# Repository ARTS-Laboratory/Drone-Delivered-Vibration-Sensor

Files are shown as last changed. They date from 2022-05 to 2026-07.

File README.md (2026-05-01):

# Drone Delivered Vibration Sensor
UAV deployable sensor package for vibration-based structural health monitoring.

<p align="center">
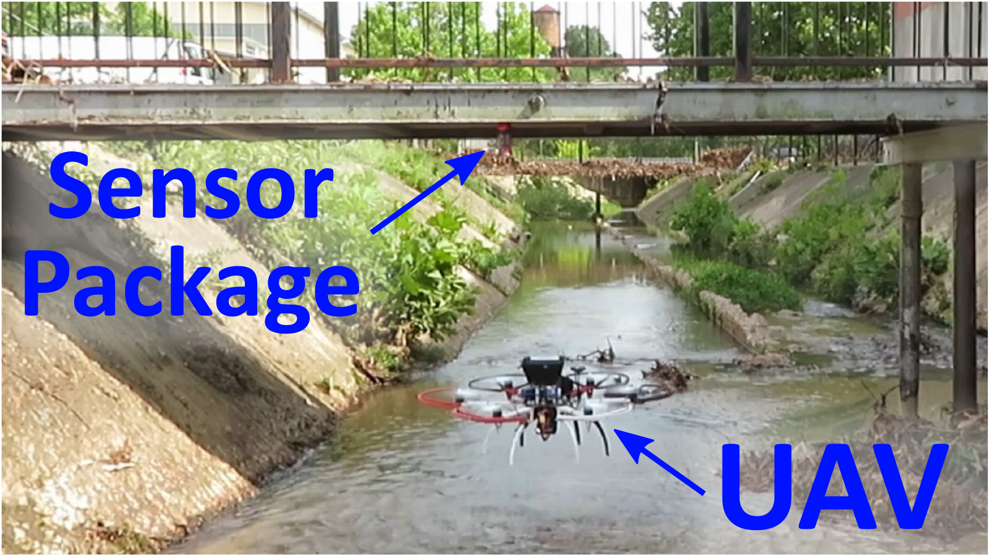
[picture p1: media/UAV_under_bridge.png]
UAV deploying sensor under bridge
  
</p>
<p align="center">
Figure 1: Video of UAV deploying a sensor package in the Rock Branch Creek at the University of South Carolina. UAV under manual control. Click the image to view the video on YouTube. 
</p>

## [System Design](System_design)
Vibration sensor package: includes sensor package software (Arduino) and hardware (circuit) files along with package frame design.

<br /><br /><br />

## Licensing and Citation

[][cc-by-sa]

This work is licensed under a
[Creative Commons Attribution-ShareAlike 4.0 International License][cc-by-sa].

[cc-by-sa]: http://creativecommons.org/licenses/by-sa/4.0/
[cc-by-sa-image]: https://licensebuttons.net/l/by-sa/4.0/88x31.png
[cc-by-sa-shield]: https://img.shields.io/badge/License-CC%20BY--SA%204.0-lightgrey.svg

Cite as:

@Misc{ARTSLabDroneDeliveredVibration,     
  author = {{ARTS-L}ab},  
  howpublished = {GitHub},    
  title  = {Drone Delivered Vibration Sensor},    
  groups = {{ARTS-L}ab},    
  url    = {https://github.com/ARTS-Laboratory/Drone-Delivered-Vibration-Sensor},   
  note = {Accessed: Month dd, yyyy},   
}

<p align="center">
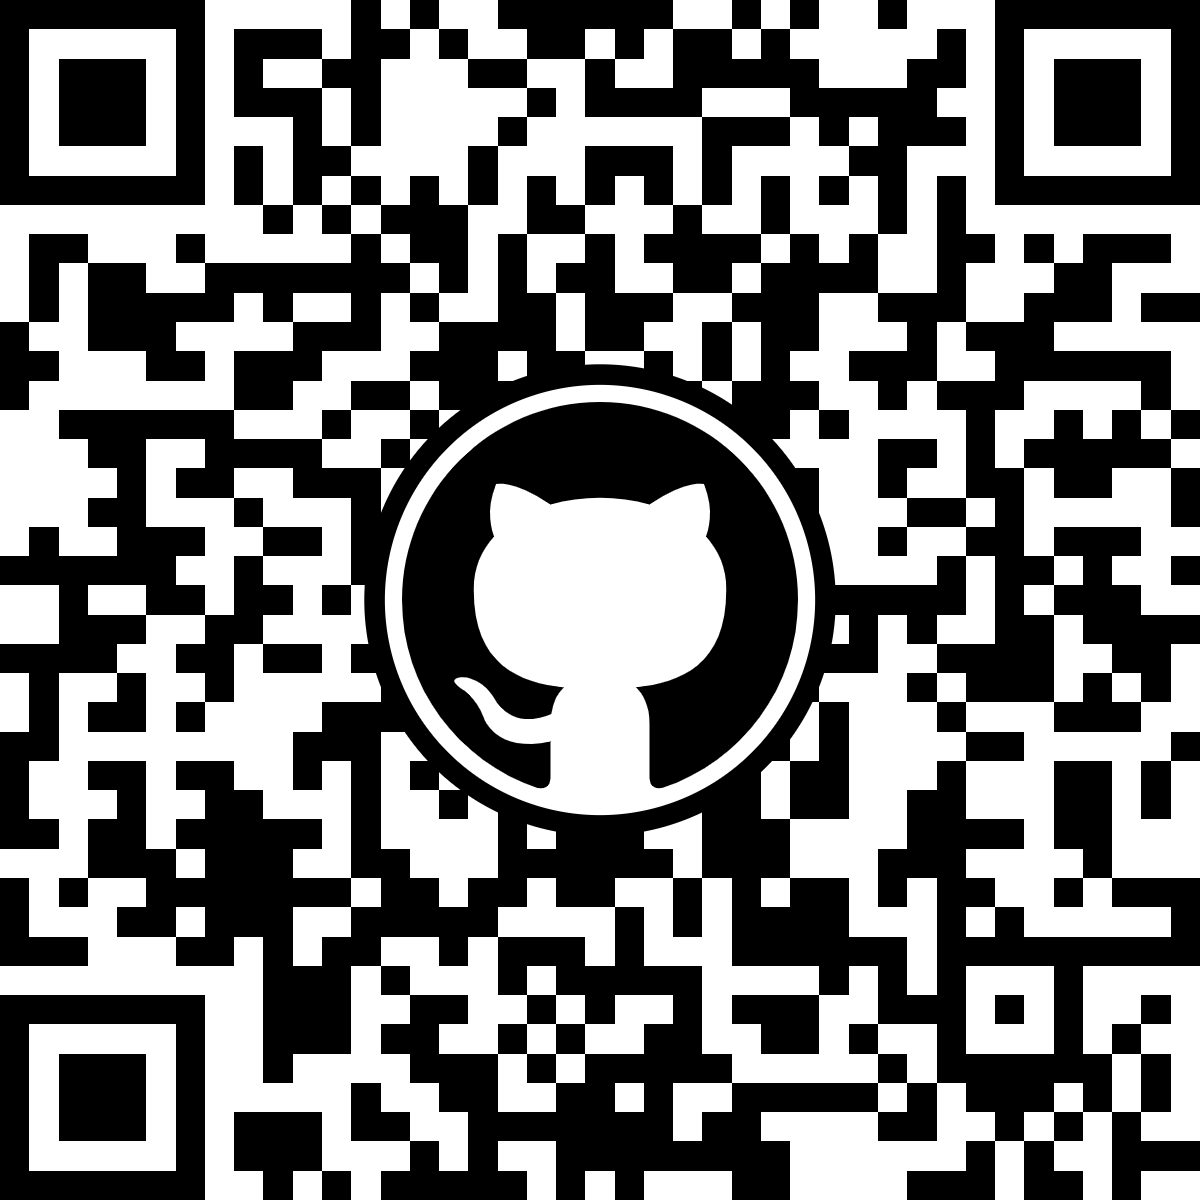
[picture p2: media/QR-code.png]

</p>
<p align="center">
QR code for repo.
</p>

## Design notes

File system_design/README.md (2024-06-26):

# System Design
The versions of the sensor package are all named after steel bridges.

## Forth
Records to local storage without wireless data transfer.

## Brooklyn
Designed for modal analysis using a network of sensors.

## Sydney Harbour
Automated frequency tracking and edge computing for rapid structural assessment. 

## Bayonne
Smart sensing node with online signal compensation.

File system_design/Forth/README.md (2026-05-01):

# Forth
Records to local storage without wireless data transfer.

## V0.1.0
A direct copy of Brooklyn V0.3 which included RTC and SD card, with no RF communication

## V0.2.0
Updated labels and silk screen symbols

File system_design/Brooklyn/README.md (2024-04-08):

# Brooklyn
Designed for modal analysis using a network of sensors.

## Version 0.1
1. Joud's Work
1. Basic package with wireless control. 

## Version 0.2
1. Ryan's Work
1. Focused on reducing package footprint while improving manufacturability.
1. Creating a stable package with options for different situations.

## Version 0.3
1. Ryan's Work
1. Same base package but includes RF and RTC for wireless synchronization.

## Version 0.4
1. Ryan's Work
1. Focused on improving the RF functionality.
1. More organized PCB.

## Version 0.5
1. Ryan's Work
1. Focused on multilayered PCB with the same base package.
1. In progress.

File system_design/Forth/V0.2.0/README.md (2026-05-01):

# Forth V0.2.0

* This uses kicad-9.0.5 -->  https://downloads.kicad.org/kicad/windows/explore/stable/download/kicad-9.0.5-x86_64.exe

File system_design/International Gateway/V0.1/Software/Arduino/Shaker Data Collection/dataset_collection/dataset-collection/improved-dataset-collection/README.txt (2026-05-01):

Author: Davis Breci
I was tasked to locate the cause for the variability of signal synchronization. The purpose of this file is to make a case for the modified dataset-collection.ino file included in this directory.

Within the original file's recordData function, the loop intended to collect data at fixed rate contained this line of code:
endTime = micros() + delayTime;
which calculates the end of each interval based on the start time of that interval.
This results in drift over time, as there is no constant reference point for timing. Consequently, the frequency of the data collection is less than 400Hz by a significant and variable amount.

This issue is addressed in the updated file.
The methodology is to synchronize the board's start time as much as possible, minimize the potential for random interruptions, and maintain a constant frequency by keeping time relative to the start time.
The start time delay measured with an oscilloscope is about 1-2ns, about one clock cycle on the Teensy 4.0.
All code that is not time-critical is executed outside the core data collection loop, particularly the slow Serial.println calls.
endTime is simply the start time + delayTime*(iterator).

Potential areas for improvement:
The most obvious thing to test is using a function generator as the trigger, rather than a wait loop.

Other files in this directory:
Screenshots of data taken with the updated code, with particular emphasis on the signals' minimally delayed response to a pulse, even 20+ seconds into recording.
A data csv file, and
A very crappy python script I used to make the plots.

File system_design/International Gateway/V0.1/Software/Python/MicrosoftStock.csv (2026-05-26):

index | date | open | high | low | close | volume | Name
390198 | 2013-02-08 | 27.35 | 27.71 | 27.31 | 27.55 | 33318306 | MSFT
390199 | 2013-02-11 | 27.65 | 27.92 | 27.5 | 27.86 | 32247549 | MSFT
390200 | 2013-02-12 | 27.88 | 28.0 | 27.75 | 27.88 | 35990829 | MSFT
390201 | 2013-02-13 | 27.93 | 28.11 | 27.88 | 28.03 | 41715530 | MSFT
390202 | 2013-02-14 | 27.92 | 28.06 | 27.87 | 28.04 | 32663174 | MSFT
390203 | 2013-02-15 | 28.04 | 28.16 | 27.875 | 28.01 | 49650538 | MSFT
390204 | 2013-02-19 | 27.8801 | 28.09 | 27.8 | 28.045 | 38804616 | MSFT
390205 | 2013-02-20 | 28.13 | 28.2 | 27.83 | 27.87 | 44109412 | MSFT
390206 | 2013-02-21 | 27.74 | 27.74 | 27.23 | 27.49 | 49078338 | MSFT
390207 | 2013-02-22 | 27.68 | 27.76 | 27.48 | 27.76 | 31425726 | MSFT
390208 | 2013-02-25 | 27.97 | 28.05 | 27.37 | 27.37 | 48011248 | MSFT
390209 | 2013-02-26 | 27.38 | 27.6 | 27.34 | 27.37 | 49917353 | MSFT
390210 | 2013-02-27 | 27.42 | 28.0 | 27.33 | 27.81 | 36390889 | MSFT
390211 | 2013-02-28 | 27.88 | 27.97 | 27.74 | 27.8 | 35836861 | MSFT
390212 | 2013-03-01 | 27.72 | 27.98 | 27.52 | 27.95 | 34849287 | MSFT
390213 | 2013-03-04 | 27.85 | 28.15 | 27.7 | 28.15 | 38163549 | MSFT
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

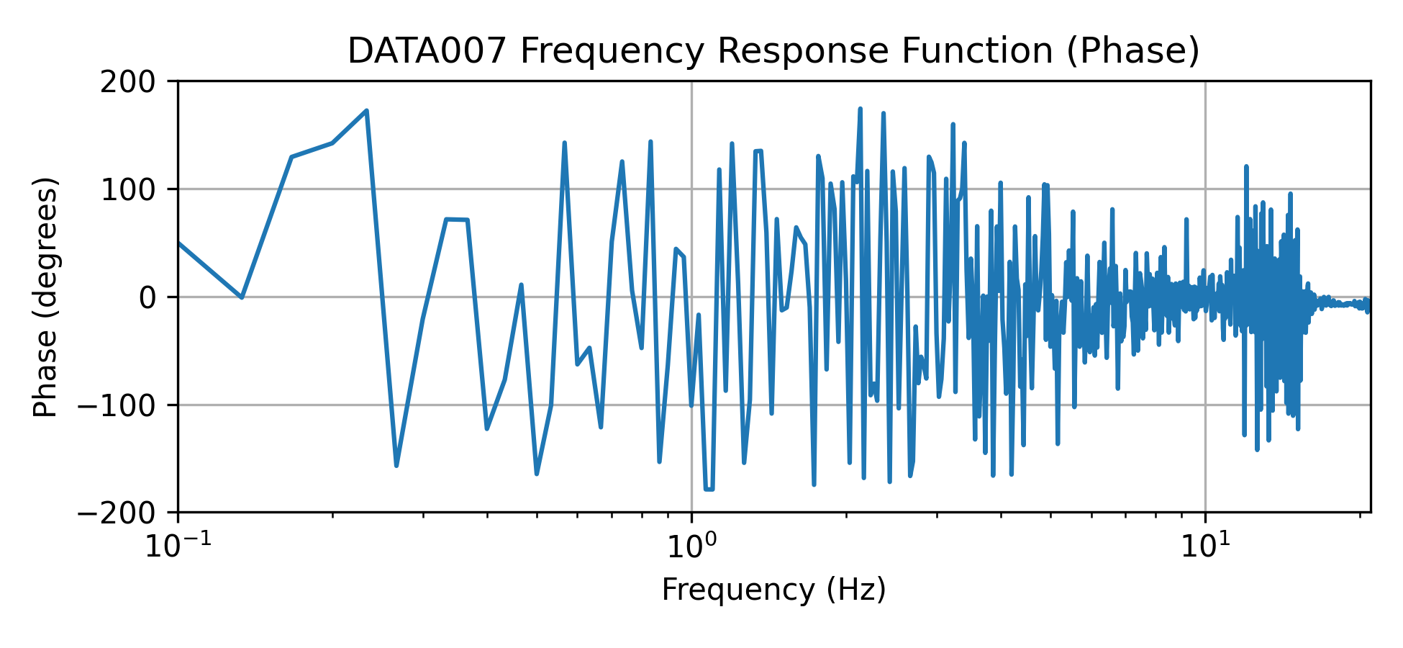
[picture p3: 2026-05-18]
system_design/International Gateway/V0.1/Software/Arduino/Shaker Data Collection/DATA007_FRF_Phase.png

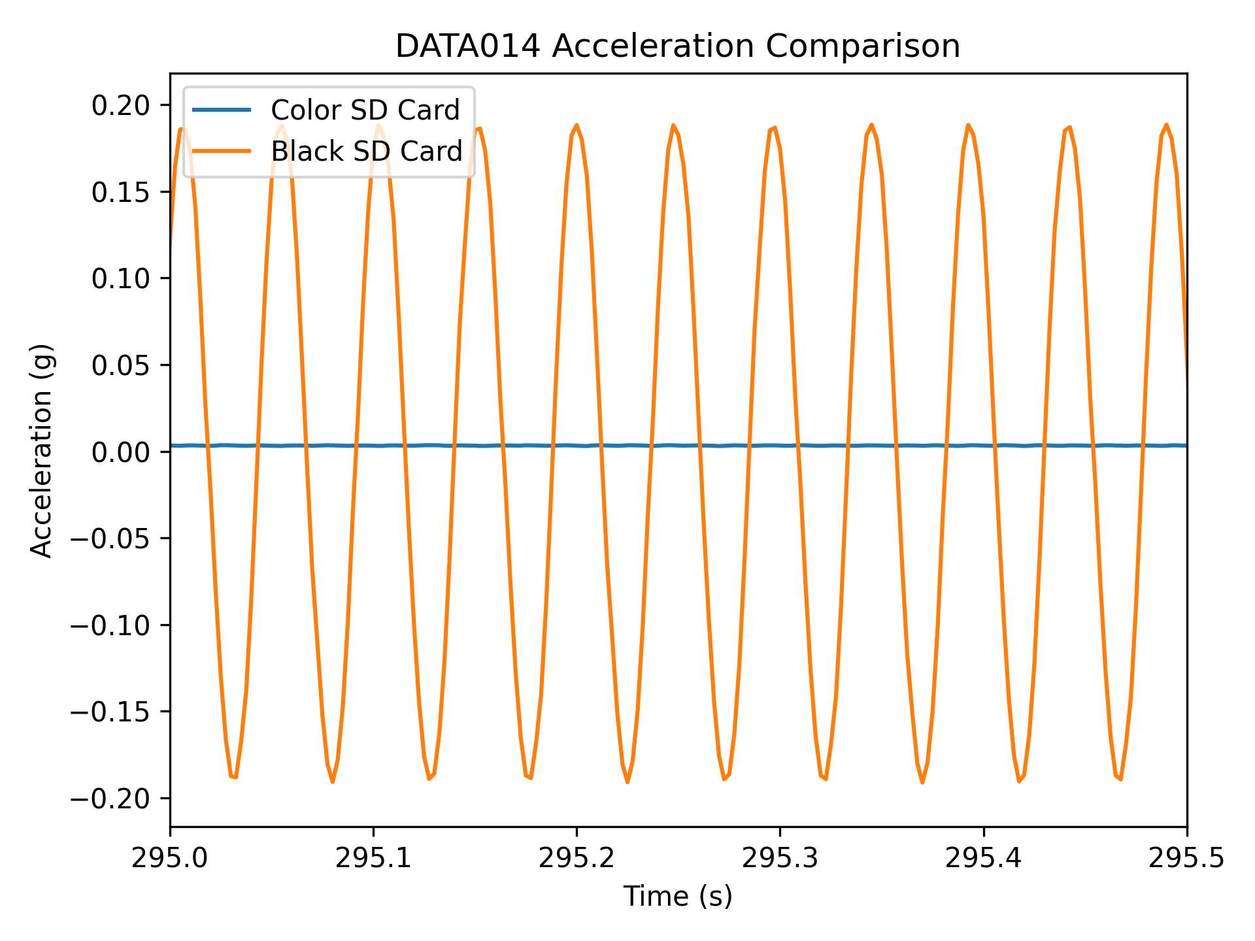
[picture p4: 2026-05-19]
system_design/International Gateway/V0.1/Software/Arduino/Shaker Data Collection/DATA014_Zoomed_Acceleration_Comparison.png

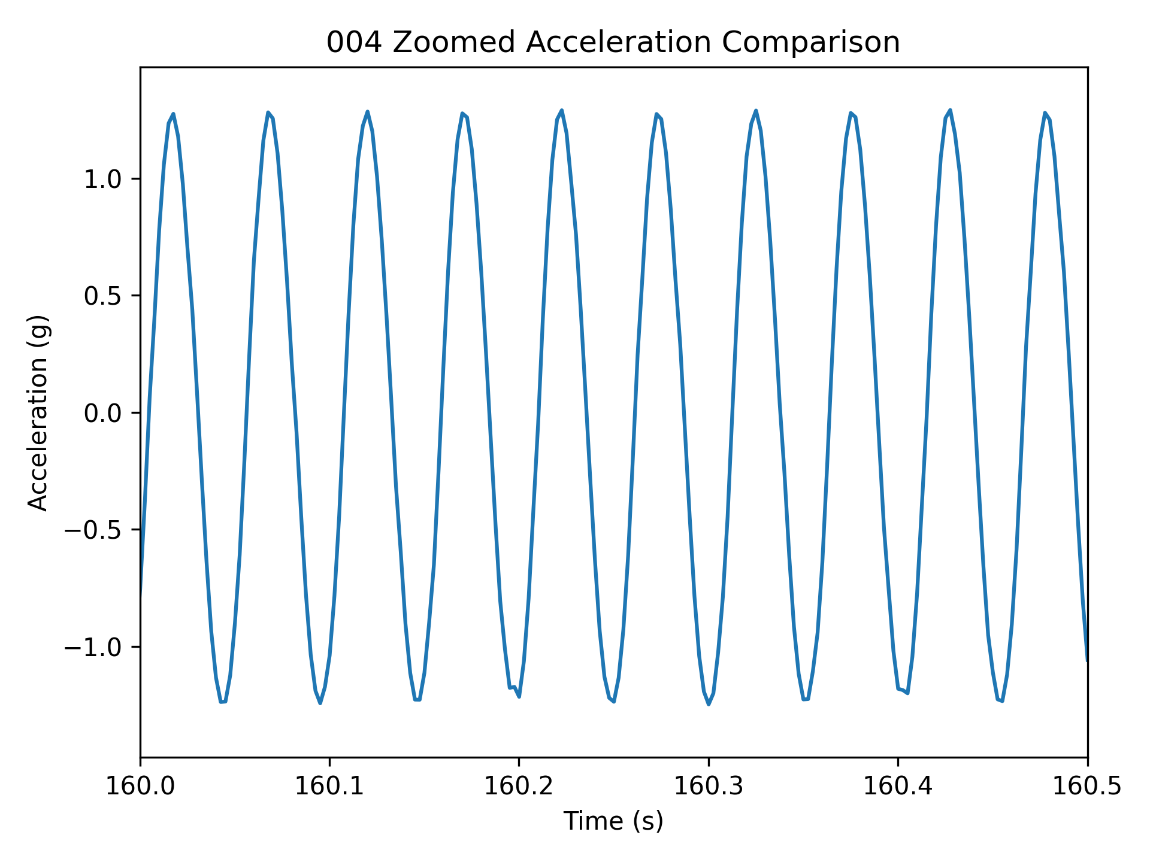
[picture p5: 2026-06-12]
system_design/International Gateway/V0.1/Software/Arduino/Shaker Data Collection/004_160_Acceleration_Comparison.png

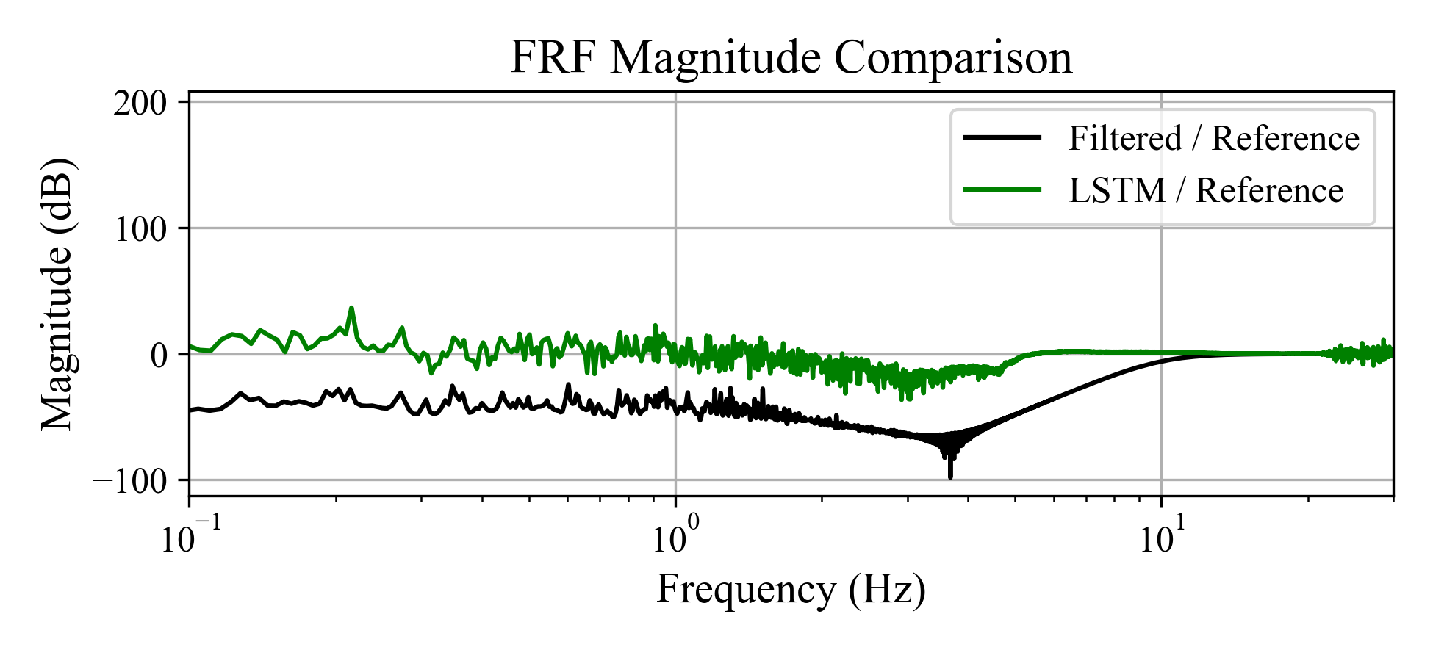
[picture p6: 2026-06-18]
system_design/International Gateway/V0.1/Software/Arduino/Shaker Data Collection/005_100Epoch_FRF_Magnitude_Comparison.png

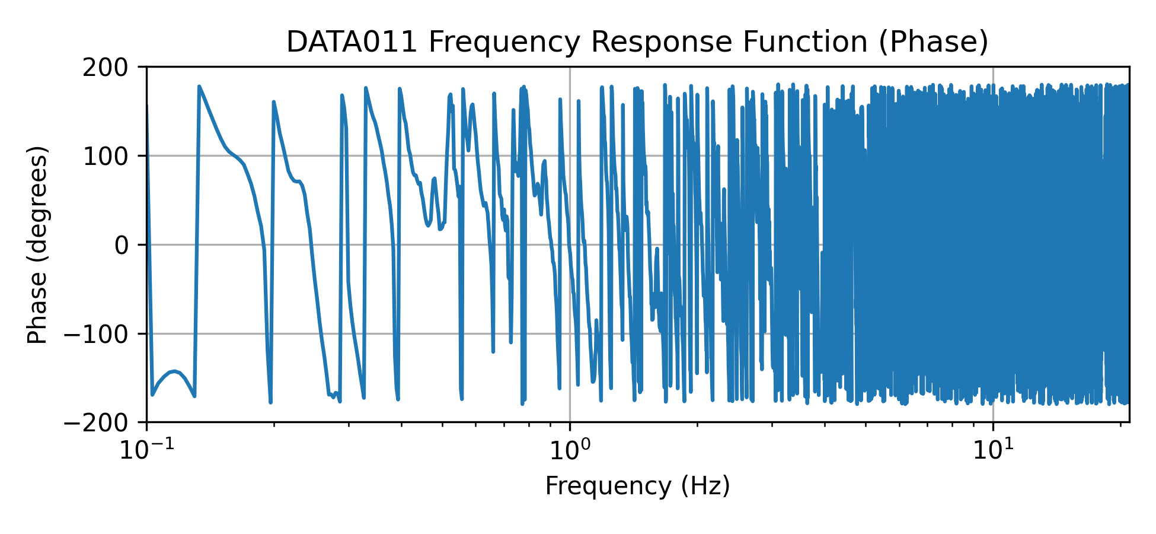
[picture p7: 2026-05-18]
system_design/International Gateway/V0.1/Software/Arduino/Shaker Data Collection/DATA011_FRF_Phase.png

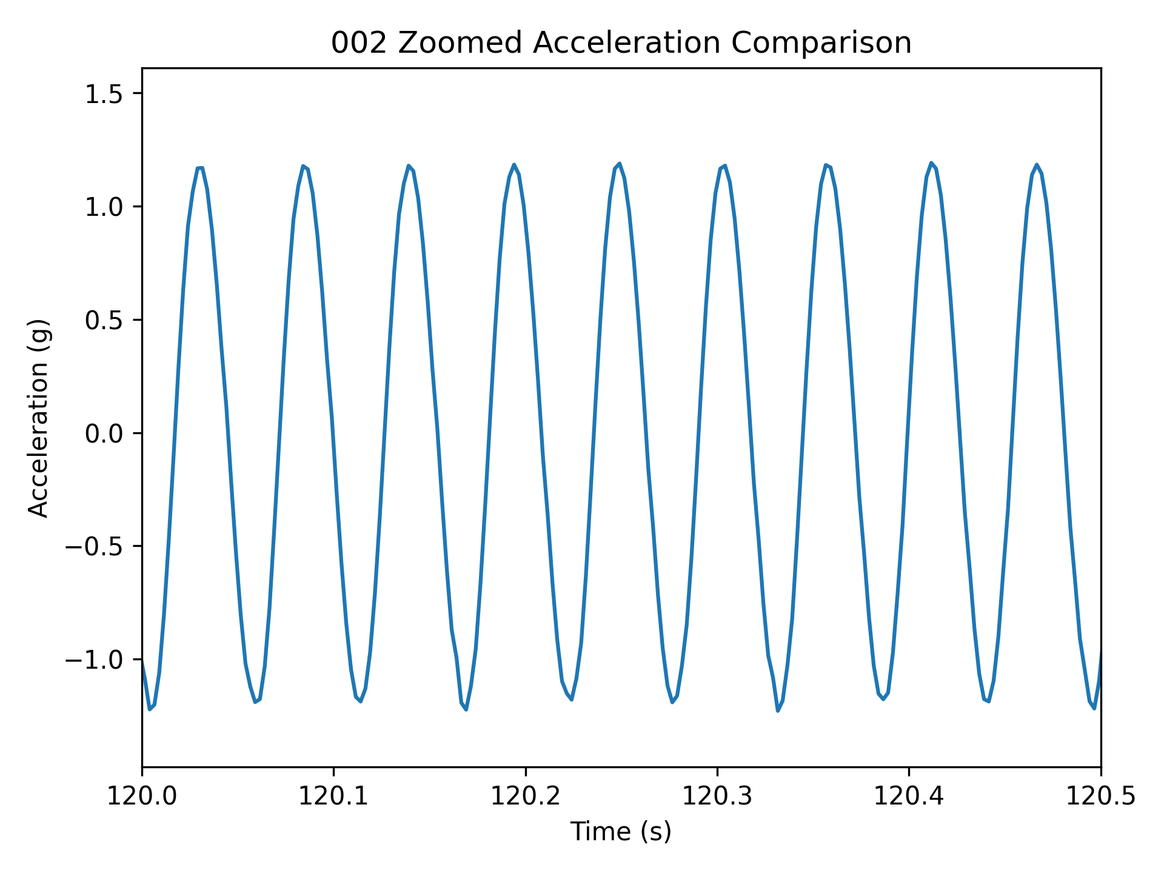
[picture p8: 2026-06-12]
system_design/International Gateway/V0.1/Software/Arduino/Shaker Data Collection/002_120_Acceleration_Comparison.png

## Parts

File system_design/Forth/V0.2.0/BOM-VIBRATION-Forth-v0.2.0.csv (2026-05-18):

Designator | Component | Amount in Inventory | Amount Per Package | Individual Cost | Total Cost | Vendor 1 | Vendor 2 | Vendor 3 | Vendor 4 | Vendor 5 | Vendor 6
Teesny 4.0 | Teensy 4.0 Development Board | 0 | 1 | 23.99 | 23.99 | https://www.digikey.com/en/products/detail/sparkfun-electronics/15583/10384551 | https://www.digikey.com/en/products/detail/sparkfun-electronics/28368/26266461 | https://www.microcenter.com/product/699942/TEENSY_40_Development_Board;_ARM_Cortex-M7_at_600_MHz;_1984K_Flash;_1024K_RAM_(512K_tightly_coupled);_1K_EEPROM | https://www.sparkfun.com/teensy-4-0.html
3-Axis Accelerometer | SCA3300 D01 | 3 | 1 | 36 | 36 | https://www.digikey.com/en/products/detail/murata-electronics/SCA3300-D01-1/7035232?gclsrc=aw.ds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 | https://www.mouser.com/ProductDetail/Murata-Electronics/SCA3300-D01-1?qs=u4fy%2FsgLU9PJXg1inqbWiw%3D%3D&mgh=1 | https://www.mouser.com/ProductDetail/Murata-Electronics/SCL3300-D01-10?qs=gZXFycFWdAOFydYBLsvu8Q%3D%3D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
Micro SD card slot/tray | MICROSD CARD BFF QT PY/XIAO | 0 | 1 | 6.5 | 6.5 | https://www.digikey.com/en/products/detail/sparkfun-electronics/13743/5881845?gclsrc=aw.ds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 | https://www.digikey.com/en/products/detail/adafruit-industries-llc/5683/18073185?gclsrc=aw.ds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 | https://abra-electronics.com/robotics-embedded-electronics/breakout-boards/storage/bb-microsd-tf-micro-sd-card-board-3-3v-mini-tf.html | https://www.amazon.com/ANMBEST-Adapter-Interface-Conversion-Arduino/dp/B08CMLG4D6
DS3231 real-time clock | DS3231M+ | 1 | 1 | 11.96 | 11.96 | https://www.digikey.com/en/products/detail/analog-devices-inc-maxim-integrated/DS3231M/2402420 | https://www.mouser.com/ProductDetail/Analog-Devices-Maxim-Integrated/DS3231M%2b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
N42 permanent magnet | Q063L-N42 | 1-1/2"L x 1-1/2"W x 1/16"T Neodymium Block Magnet | 0 | 1 | 6.46 | 6.46 | https://www.kjmagnetics.com/dx46-neodymium-disc-magnet
2s 7.4V LiPo battery | Zeee 2S Lipo Battery 1500mAh 7.4V 60C with Deans Plug | 0 | 1 | 18 | 18 | https://zeeebattery.com/products/zeee-7-4v-60c-1500mah-2s-lipo-battery-deans-plug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 | https://www.digikey.com/en/products/detail/sparkfun-electronics/11855/5271297?gclsrc=aw.ds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 | https://www.ebay.com/itm/374993811392?chn=ps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
CR-1025 3V Li+ coin cell | CR-1025-ND | 0 | 1 | 1.09 | 1.09 | https://www.digikey.com/en/products/detail/panasonic-energy/CR-1025-BN/269738 | https://www.ebay.com/itm/365610739537?chn=ps&google_free_listing_action=view_item
RTC coin cell holder | 2718 | 1 | 1 | 1.61 | 1.61 | https://www.digikey.com/en/products/detail/kitronik-ltd/2718/8635448 | https://www.mouser.com/ProductDetail/Harwin/S8211-46R?qs=Qom7kyPojXb0DJM7n6BsBw%3D%3D&mgh=1
Main PCB | Main board | 0 | 1 | 8.23 | 8.23 | https://oshpark.com/
Slide switch | SPDT | 1 | 1 | 0.38 | 0.38 | https://www.digikey.com/en/products/detail/same-sky-formerly-cui-devices/SLW-129956-4A-RA-N-D/24399223
Micro SD card | Gigastone 8GB 10-Pack Micro SD Card, Full HD Video 80MB/s Micro SDHC Class 10 | 0 | 1 | 8.24 | 8.24 | https://www.staples.com/centon-micro-8gb-sdhc-memory-card-uhs1-5-pack-s1-msdhu1-8g-5-b/product_24298979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 | https://www.staples.com/transcend-8gb-microsdhc-memory-card-class-10-ts8gusdhc10/product_IM1LK3226 | https://www.cdwg.com/product/transcend-flash-memory-card-8-gb-microsd/3181432?pfm=srh | https://www.cdwg.com/product/kingston-industrial-flash-memory-card-8-gb-microsdhc-uhs-i/6669743?pfm=srh | https://business.walmart.com/ip/Gigastone-8GB-Micro-SD-Card-FHD-Video-UHS-I-U1-Class-10-Surveillance-Security-Action-Cameras-Drone-Dash-Cams-5-Pack-5x8GB-GS-2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 | https://www.amazon.com/Gigastone-10-Pack-Surveillance-Security-Action/dp/B0876H387X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
LED | L314ED | 1 | 1 | 0.2 | 0.2 | https://www.digikey.com/en/products/detail/liteon/LTL-4231N/214440 | https://www.lvelectronics.com/details/item?itemid=AOP%20L314ED
Resistors | RES SMD 221 OHM 1% 1/4W 1206 | 10 | 1 | 0.1 | 0.1 | https://www.digikey.com/en/products/detail/bourns-inc/CR1206-FX-2210ELF/2562869
Capacitors 0.1uF | C1206S104K5RACAUTO 0.1 uF 10% 50V Ceramic Capacitor X7R 1206 (3216 Metric) | 10 | 4 | 0.48 | 1.92 | https://www.digikey.com/en/products/detail/kemet/C1206S104K5RACAUTO/10232834 | https://www.mouser.com/ProductDetail/KEMET/C1206S104K5RACAUTO?qs=ds50AKTGxA9C%252BOGFjvBCPg%3D%3D
Fuse board | SF-0603S050-2 | 5 | 1 | 0.68 | 0.68 | https://www.digikey.com/en/products/detail/bourns-inc/SF-0603S050-2/2563500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
3.3V regulator | TC1262-3.3VDBTR | 1 | 1 | 0.69 | 0.69 | https://www.digikey.com/en/products/detail/microchip-technology/TC1262-3-3VDBTR/443194
5V regulator | MIC5239-5.0YS-TR | 2 | 1 | 3.58 | 3.58 | https://www.digikey.com/en/products/detail/microchip-technology/MIC5239-5-0YS-TR/2346595 | https://www.microchipdirect.com/product/MIC5239-5.0YS-TR | https://www.mouser.com/ProductDetail/Microchip-Technology/MIC5239-5.0YS-TR?qs=U6T8BxXiZAVR02O8mv9RNQ%3D%3D
M2 nut | M2 nut | 100 | 3 | 2.37 | 7.11 | https://www.grainger.com/product/Hex-Nut-Std-Hex-22UK72?opr=ILOF
M2 bolt | M2 bolt | 100 | 3 | 6.92 | 20.76 | https://www.grainger.com/product/Machine-Screw-M2x0-40-Thread-856Z51
 |  |  |  | Total Cost | 157.5

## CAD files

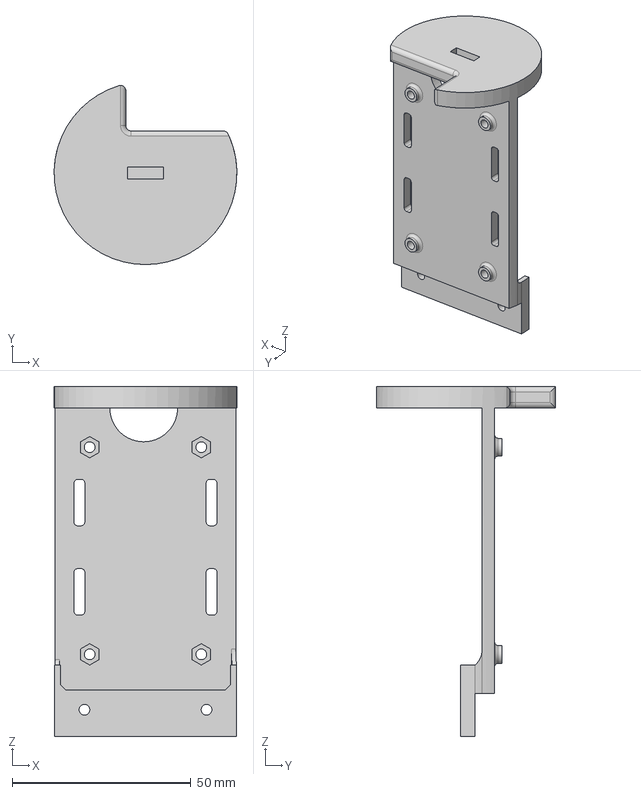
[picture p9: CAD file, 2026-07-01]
system_design/Forth/V0.2.0/Hardware/CAD/sensor frame/Part4Updated.step
51.2 x 50.2 x 98.0 mm

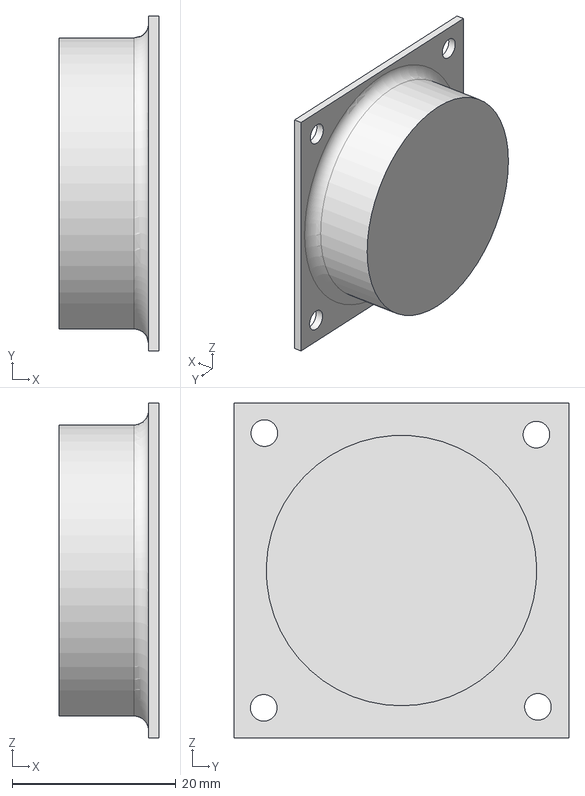
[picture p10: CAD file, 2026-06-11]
system_design/Forth/V0.2.0/Hardware/CAD/sensor frame/MagnetCap.stp
12.2 x 40.9 x 40.9 mm

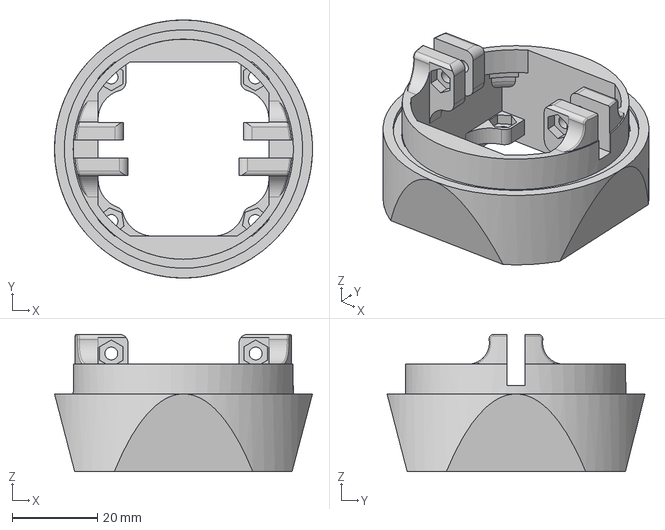
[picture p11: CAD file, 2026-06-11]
system_design/Forth/V0.2.0/Hardware/CAD/sensor frame/Part4Bottom.step
60.6 x 60.6 x 32.3 mm

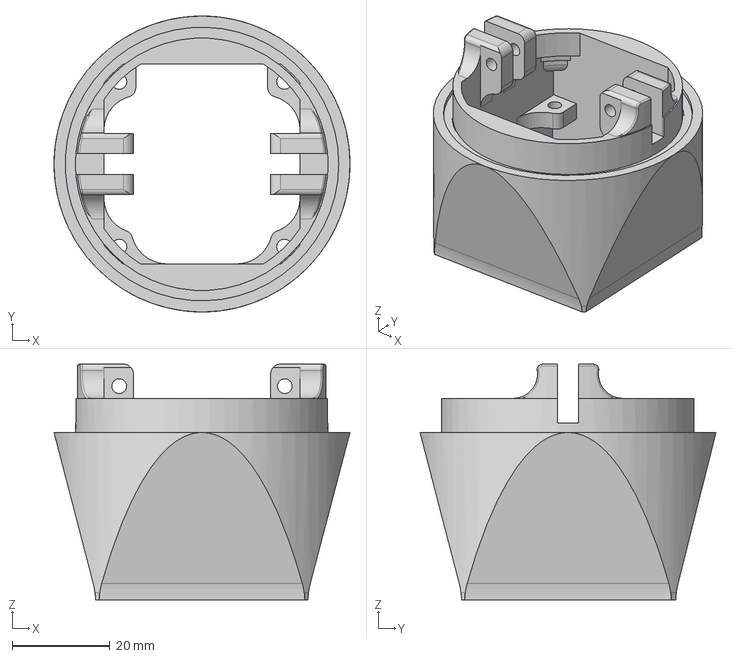
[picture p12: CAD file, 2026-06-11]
system_design/Forth/V0.2.0/Hardware/CAD/sensor frame/Part4OtherBottom.step
60.6 x 60.6 x 48.3 mm

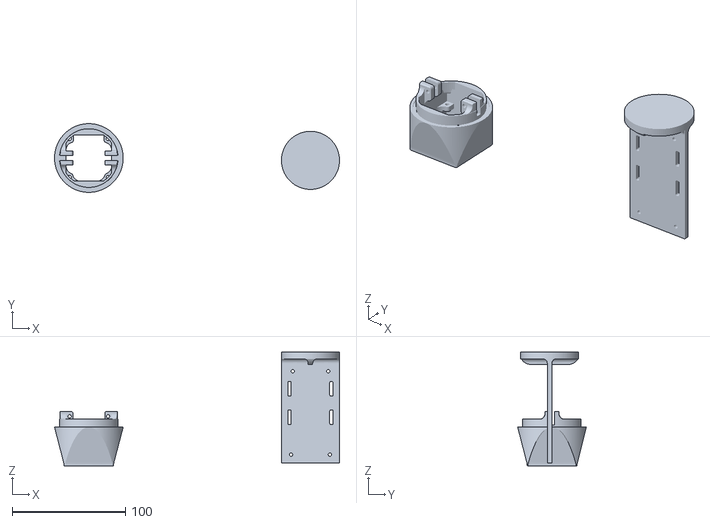
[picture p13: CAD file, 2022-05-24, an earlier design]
system_design/Forth/V0.1.0/Hardware/Frame/Sensor Package Housing Unit.stl
251.3 x 60.6 x 100.5

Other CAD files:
system_design/Forth/V0.2.0/Hardware/CAD/sensor frame/Part4Switch.step
system_design/Forth/V0.2.0/Hardware/CAD/sensor frame/Part4.step
system_design/Forth/V0.1.0/Hardware/Frame/PCB_HousingUnit.f3d
system_design/Forth/V0.2.0/Hardware/CAD/sensor frame v1.f3d
system_design/Forth/V0.2.0/Hardware/CAD/sensor frame/Component2.ipt
system_design/Forth/V0.2.0/Hardware/CAD/sensor frame/MagnetCap.3mf
system_design/Forth/V0.2.0/Hardware/CAD/sensor frame/MagnetCap.ipt
system_design/Forth/V0.2.0/Hardware/CAD/sensor frame/OldVersions/MagnetCap.0003.ipt
system_design/Forth/V0.2.0/Hardware/CAD/sensor frame/OldVersions/UpatedSensorFrame.0001.ipt
system_design/Forth/V0.2.0/Hardware/CAD/sensor frame/Part4.ipt
system_design/Forth/V0.2.0/Hardware/CAD/sensor frame/UpatedSensorFrame.ipt
system_design/Forth/V0.2.0/Hardware/CAD/sensor frame/sensor frame.iam
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

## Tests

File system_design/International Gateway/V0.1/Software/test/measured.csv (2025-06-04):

-2.875130916445163901e-02
-4.373330916445163086e-02
-5.736130916445163208e-02
-7.172630916445163485e-02
-8.455330916445163991e-02
-9.480730916445163914e-02
-1.020343091644516365e-01
-1.067743091644516445e-01
-1.104643091644516434e-01
-1.125543091644516380e-01
-1.126743091644516470e-01
-1.100943091644516342e-01
-1.055243091644516434e-01
-9.955630916445164236e-02
-9.281130916445164136e-02
-8.460030916445164528e-02
-7.443930916445164192e-02
-6.330030916445164579e-02
-5.093430916445163686e-02
-3.915230916445163606e-02
-2.658830916445163728e-02
-1.131230916445163590e-02
3.898990835548364186e-03
1.778269083554836344e-02
3.148369083554836828e-02
4.683369083554836387e-02
6.213469083554836597e-02
7.449469083554835502e-02
8.573069083554836489e-02
9.728269083554835772e-02
1.058856908355483573e-01
1.126156908355483571e-01
1.175056908355483626e-01
1.199556908355483564e-01
1.188156908355483543e-01
1.151456908355483616e-01
1.099656908355483576e-01
1.018656908355483615e-01
9.194869083554835232e-02
8.118969083554836152e-02
6.926369083554835548e-02
5.594369083554836392e-02
4.069269083554836325e-02
2.445669083554836282e-02
6.941890835548363177e-03
-9.103809164451635502e-03
-2.431930916445163710e-02
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

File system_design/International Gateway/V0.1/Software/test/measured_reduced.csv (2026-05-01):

-6.413430916445164720e-02
-6.432130916445163993e-02
-6.292430916445164446e-02
-6.076230916445163333e-02
-5.911530916445163070e-02
-5.748930916445163519e-02
-5.469330916445163532e-02
-5.154430916445163630e-02
-4.708130916445163461e-02
-4.368630916445163243e-02
-3.841530916445163452e-02
-3.396930916445163595e-02
-2.946730916445163689e-02
-2.436130916445163747e-02
-1.841330916445163557e-02
-1.218430916445163541e-02
-5.102909164451636427e-03
9.202608355483637894e-04
7.673390835548363556e-03
1.378769083554836489e-02
2.134169083554836310e-02
2.827069083554836423e-02
3.308869083554836360e-02
3.936669083554836940e-02
4.541169083554836422e-02
5.065969083554836688e-02
5.374269083554836929e-02
5.919869083554836486e-02
6.343769083554835764e-02
6.479769083554835774e-02
6.781969083554835465e-02
6.835469083554836234e-02
6.851769083554835882e-02
6.703769083554836361e-02
6.555569083554835252e-02
6.378769083554836072e-02
5.989669083554836904e-02
5.734269083554836832e-02
5.345069083554836870e-02
4.822969083554836528e-02
4.396669083554836932e-02
3.818169083554836390e-02
3.188969083554836492e-02
2.446069083554836335e-02
1.947469083554836250e-02
1.164069083554836528e-02
3.427990835548364121e-03
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

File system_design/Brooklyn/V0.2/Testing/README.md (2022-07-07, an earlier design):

# Testing For V0.2 of the Vibration Sensor

<p align="center">
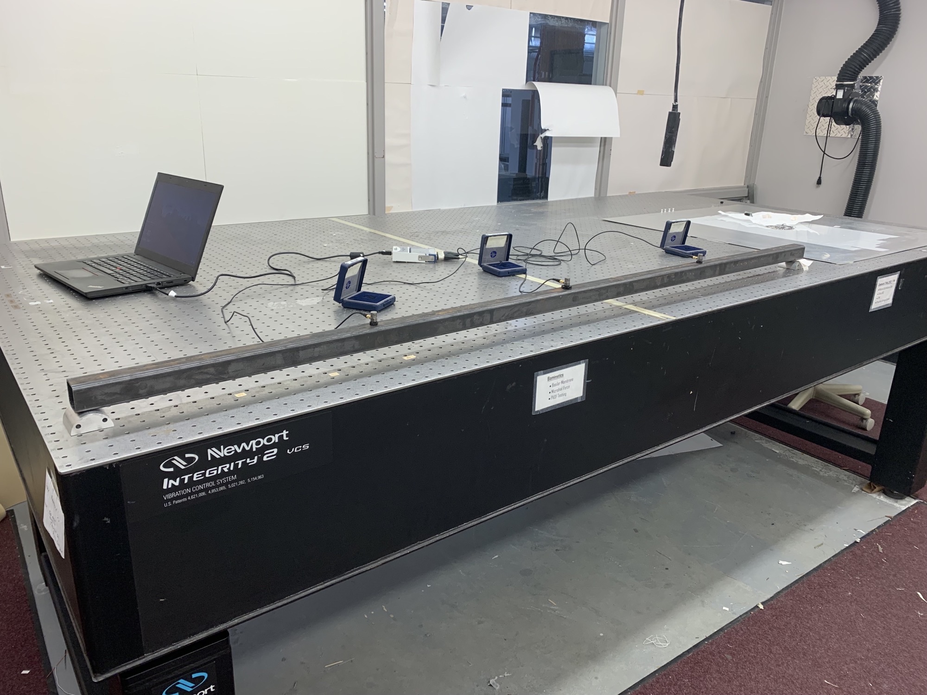
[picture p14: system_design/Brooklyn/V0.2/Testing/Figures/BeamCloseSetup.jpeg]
Beam Close Test Setup
</a> 
<p align="center">
Figure 1: Picture of the beam test with accelerometers in a close position

<p align="center">
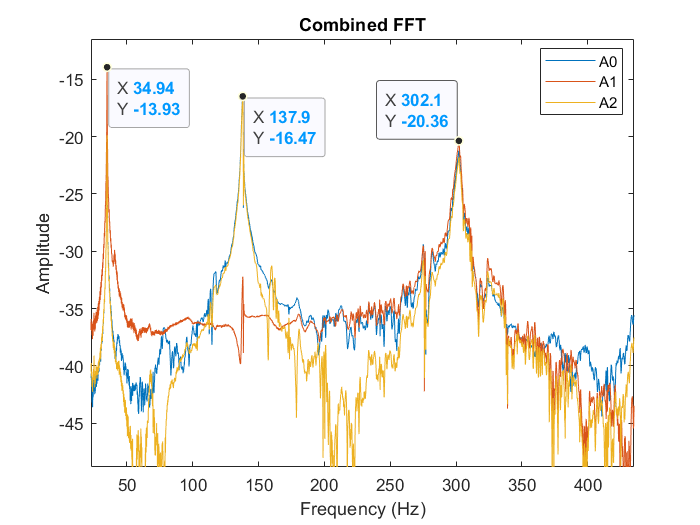
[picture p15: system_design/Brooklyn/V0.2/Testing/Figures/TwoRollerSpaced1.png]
Two Roller Spaced Test 1
</a> 
<p align="center">
Figure 2: FFT of the beam test with spaced out accelerometers and two roller supports

<p align="center">
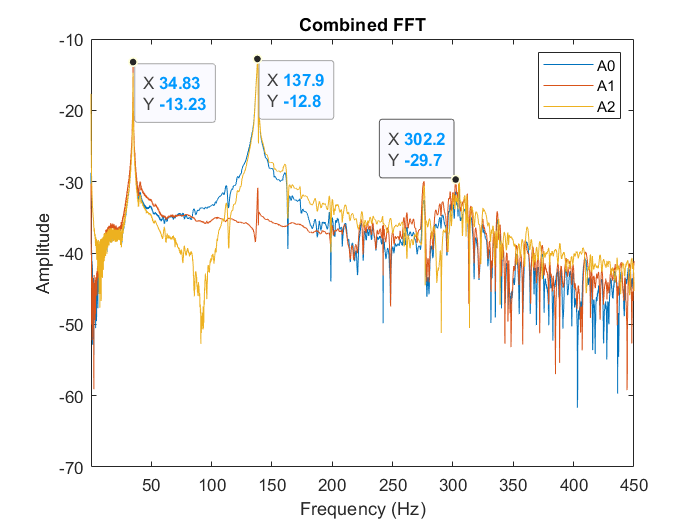
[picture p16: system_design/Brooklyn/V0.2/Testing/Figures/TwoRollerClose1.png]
Two Roller Close Test 1
</a> 
<p align="center">
Figure 3: FFT of the beam test with close accelerometers and two roller supports

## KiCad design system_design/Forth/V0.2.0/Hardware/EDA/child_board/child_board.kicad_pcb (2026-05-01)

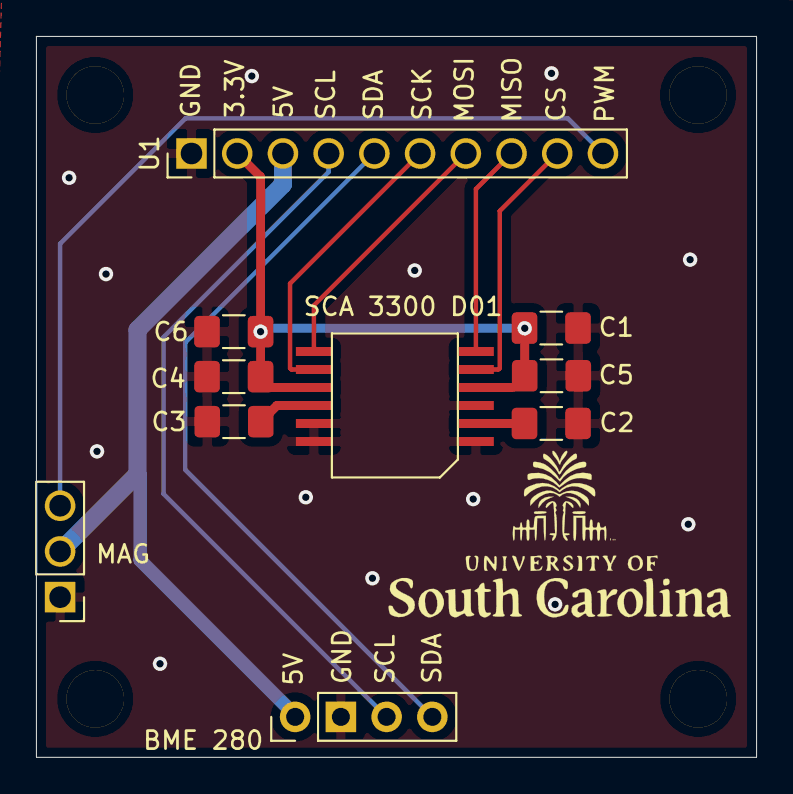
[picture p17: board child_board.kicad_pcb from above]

Board: 2 copper layers, 40.0 x 40.0 mm, 15 parts (0 on the bottom side), 12 nets.

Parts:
., .#2, .#3, .#5: MountingHole_3.2mm_M3_DIN965_Pad
.#4: .; uofsc_logo_0_75in
BME 280: BME; PinHeader_1x04_P2.54mm_Vertical
C1, C2, C3, C4, C5, C6: C_Small; C_1206_3216Metric_Pad1.42x1.75mm_HandSolder
MAG: Conn_01x03_Female; PinHeader_1x03_P2.54mm_Vertical
SCA 3300 D01: SCA_330_X1; SCA-3300 X1
U1: 10PinConnector; PinHeader_1x10_P2.54mm_Vertical

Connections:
+3V3: C1.1, C4.1, C5.2, C6.1, SCA 3300 D01.4, SCA 3300 D01.9, U1.2
GND: BME 280.2, C1.2, C2.1, C3.1, C4.2, C5.1, C6.2, MAG.1, SCA 3300 D01.1, SCA 3300 D01.3, SCA 3300 D01.11, SCA 3300 D01.12, U1.1
unnamed: C2.2, SCA 3300 D01.2
unnamed: C3.2, SCA 3300 D01.10
unnamed: BME 280.1, MAG.2, U1.3
unnamed: MAG.3, U1.10
unnamed: BME 280.3, U1.4
unnamed: BME 280.4, U1.5
unnamed: SCA 3300 D01.8, U1.6
unnamed: SCA 3300 D01.7, U1.7
unnamed: SCA 3300 D01.6, U1.8
unnamed: SCA 3300 D01.5, U1.9

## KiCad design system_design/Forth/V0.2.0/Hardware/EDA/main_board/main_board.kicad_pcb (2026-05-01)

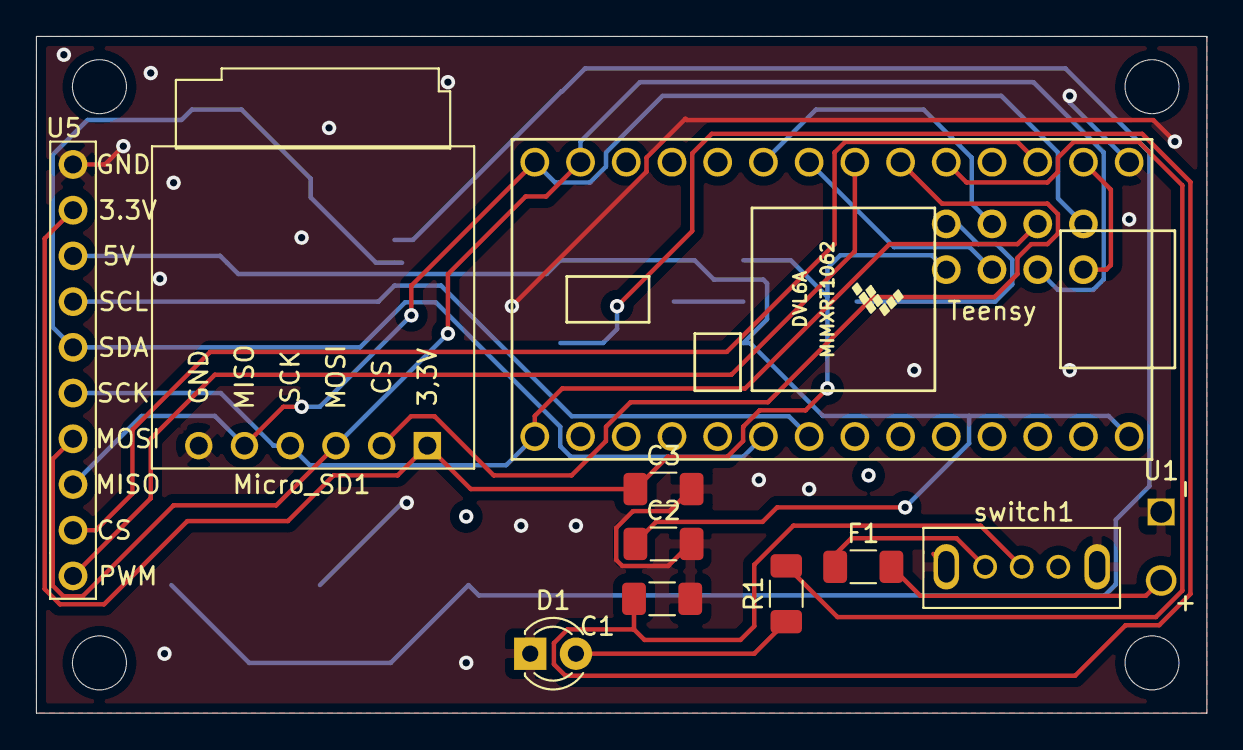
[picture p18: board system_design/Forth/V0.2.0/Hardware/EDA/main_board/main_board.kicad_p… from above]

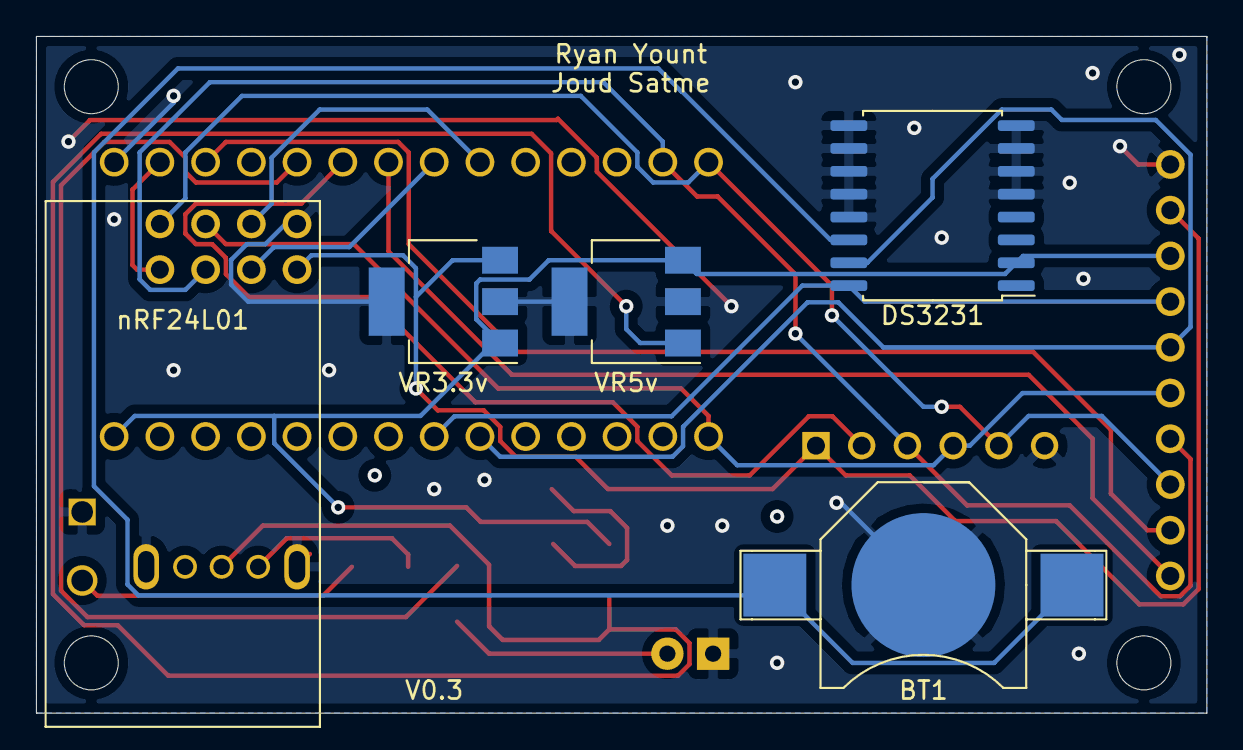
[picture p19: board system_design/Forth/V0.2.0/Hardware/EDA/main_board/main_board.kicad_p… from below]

Board: 2 copper layers, 65.0 x 37.6 mm, 16 parts (5 on the bottom side), 20 nets.

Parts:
BT1: Battery_Cell; battery_holder_10mm
C1, C2, C3: C; C_1206_3216Metric_Pad1.33x1.80mm_HandSolder
D1: LED; LED_D3.0mm
DS3231: DS3231M; SOIC-16W_7.5x10.3mm_P1.27mm
F1: Fuse; C_1206_3216Metric_Pad1.33x1.80mm_HandSolder
Micro_SD1: microSD_small; small_microSD_v2
R1: R; R_1206_3216Metric_Pad1.30x1.75mm_HandSolder
Teensy: Teensy4.0-teensy; teensy4.0
U1: power_input; XT60PW
U5: main_board_top_rail; top_rail
VR3.3v, VR5v: AP7361C-33E; SOT-223-3_TabPin2
nRF24L01: nRF24L01+
switch1: grounded_DIP_switch; grounded_switch

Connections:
GND: BT1.2, C1.2, C2.2, C3.2, D1.1, DS3231.5, DS3231.6, DS3231.7, DS3231.8, DS3231.9, DS3231.10, DS3231.11, DS3231.12, DS3231.13, Micro_SD1.6, Teensy.1, U1.1, U5.9, VR3.3v.2, VR5v.2, nRF24L01.5, switch1.4, switch1.5
unnamed: BT1.1, DS3231.14
unnamed: C1.1, VR5v.1, switch1.2
unnamed: C2.1, DS3231.2, Teensy.33, U5.7, VR3.3v.1, VR5v.3
unnamed: C3.1, Micro_SD1.1, U5.8, VR3.3v.3, nRF24L01.1
unnamed: D1.2, R1.1
unnamed: F1.1, switch1.1
unnamed: F1.2, U1.2
unnamed: Micro_SD1.2, Teensy.6
unnamed: Micro_SD1.3, Teensy.13, U5.3, nRF24L01.3
unnamed: Micro_SD1.4, Teensy.20, U5.4, nRF24L01.7
unnamed: Micro_SD1.5, Teensy.14, U5.2, nRF24L01.8
unnamed: R1.2, Teensy.5
unnamed: Teensy.2, nRF24L01.4
unnamed: Teensy.3, U5.1
unnamed: Teensy.7, U5.10
unnamed: Teensy.8, nRF24L01.2
unnamed: Teensy.9, nRF24L01.6
unnamed: DS3231.15, Teensy.25, U5.5
unnamed: DS3231.16, Teensy.26, U5.6

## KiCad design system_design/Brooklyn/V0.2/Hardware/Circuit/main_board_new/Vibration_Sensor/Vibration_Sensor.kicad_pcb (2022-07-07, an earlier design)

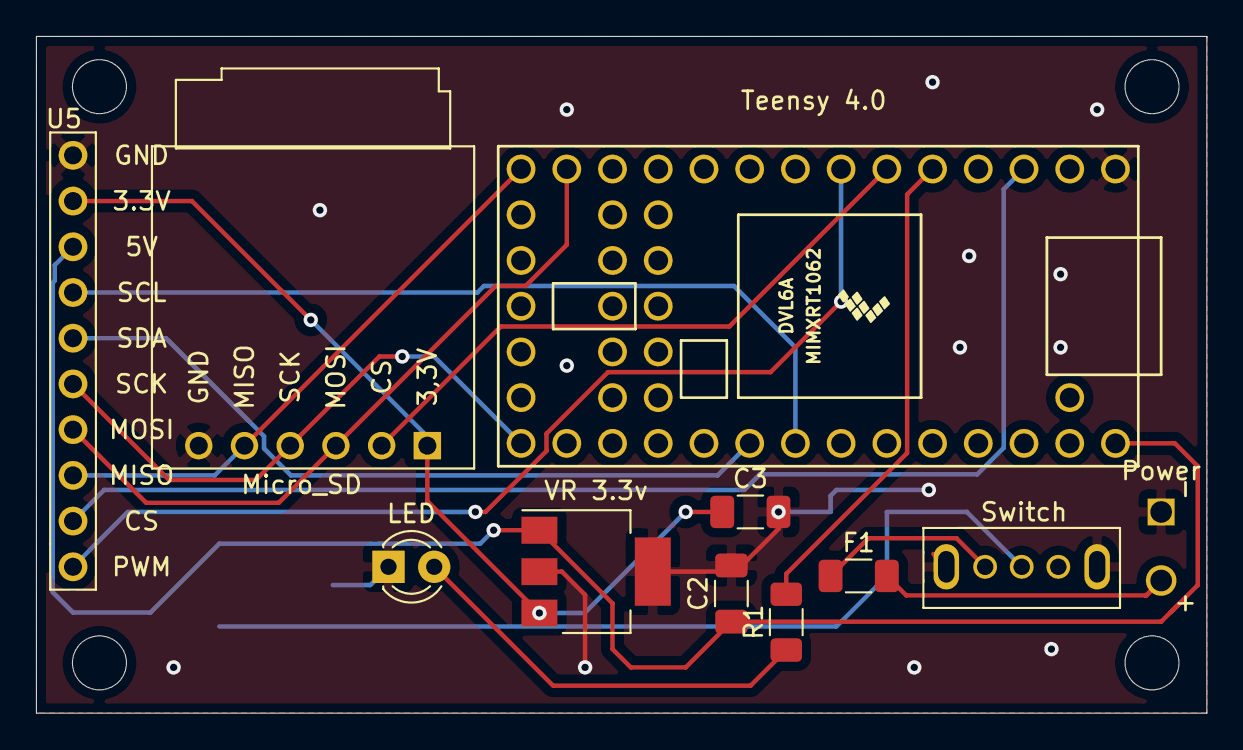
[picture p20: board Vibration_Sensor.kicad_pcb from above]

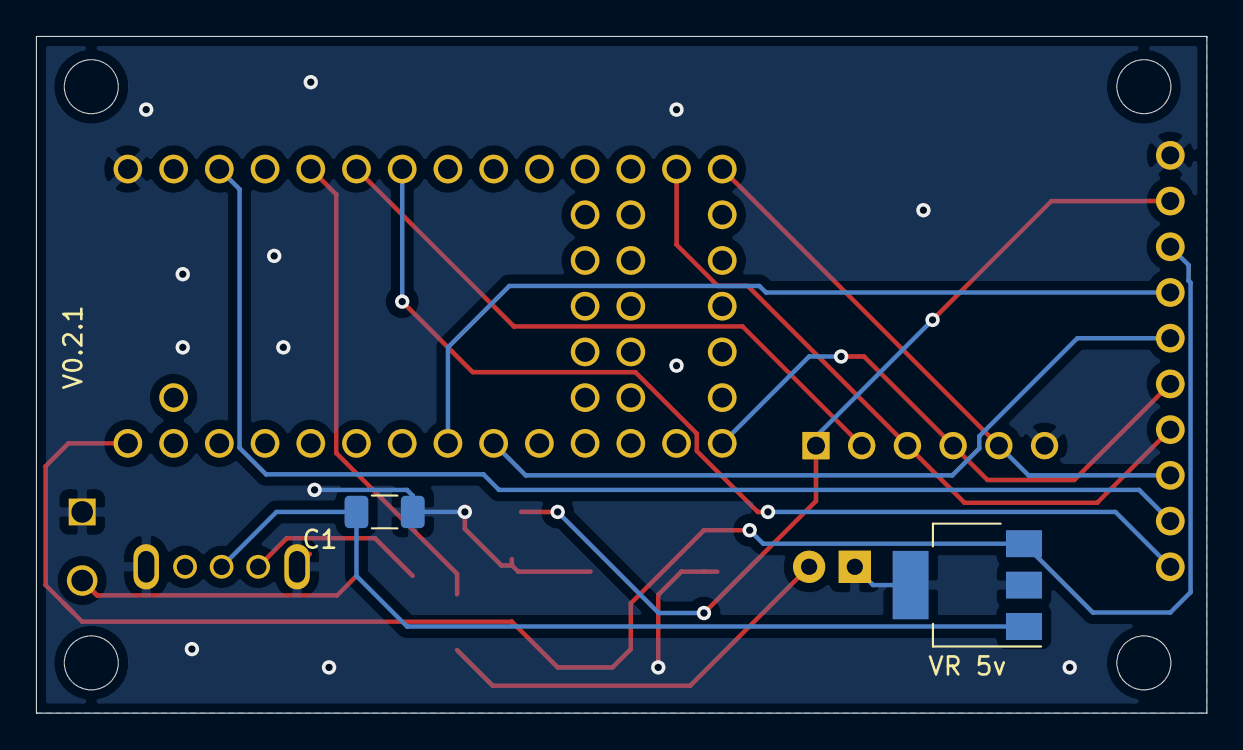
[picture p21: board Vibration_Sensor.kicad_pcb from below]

Board: 2 copper layers, 65.0 x 37.6 mm, 13 parts (3 on the bottom side), 16 nets.

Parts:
C1, C2, C3: C; C_1206_3216Metric_Pad1.33x1.80mm_HandSolder
F1: Fuse; C_1206_3216Metric_Pad1.33x1.80mm_HandSolder
LED: LED; LED_D3.0mm
Micro_SD: microSD_small; small_microSD_v2
Power: power_input; XT60PW
R1: R; R_1206_3216Metric_Pad1.30x1.75mm_HandSolder
Switch: grounded_DIP_switch; grounded_switch
Teensy 4.0: Teensy4.0-teensy; Teensy40
U5: main_board_top_rail; top_rail
VR 3.3v, VR 5v: AP7361C-33E; SOT-223-3_TabPin2

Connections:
GND: C1.2, C2.2, C3.2, LED.1, Micro_SD.6, Power.1, Switch.4, Switch.5, Teensy 4.0.1, U5.9, VR 3.3v.2, VR 5v.2
unnamed: C1.1, Switch.2, VR 5v.1
unnamed: C2.1, Teensy 4.0.33, U5.7, VR 3.3v.1, VR 5v.3
unnamed: C3.1, Micro_SD.1, U5.8, VR 3.3v.3
unnamed: LED.2, R1.1
unnamed: F1.1, Switch.1
unnamed: F1.2, Power.2
unnamed: Micro_SD.2, Teensy 4.0.6
unnamed: Micro_SD.3, Teensy 4.0.13, U5.3
unnamed: Micro_SD.4, Teensy 4.0.20, U5.4
unnamed: Micro_SD.5, Teensy 4.0.14, U5.2
unnamed: R1.2, Teensy 4.0.5
unnamed: Teensy 4.0.3, U5.1
unnamed: Teensy 4.0.7, U5.10
unnamed: Teensy 4.0.25, U5.5
unnamed: Teensy 4.0.26, U5.6

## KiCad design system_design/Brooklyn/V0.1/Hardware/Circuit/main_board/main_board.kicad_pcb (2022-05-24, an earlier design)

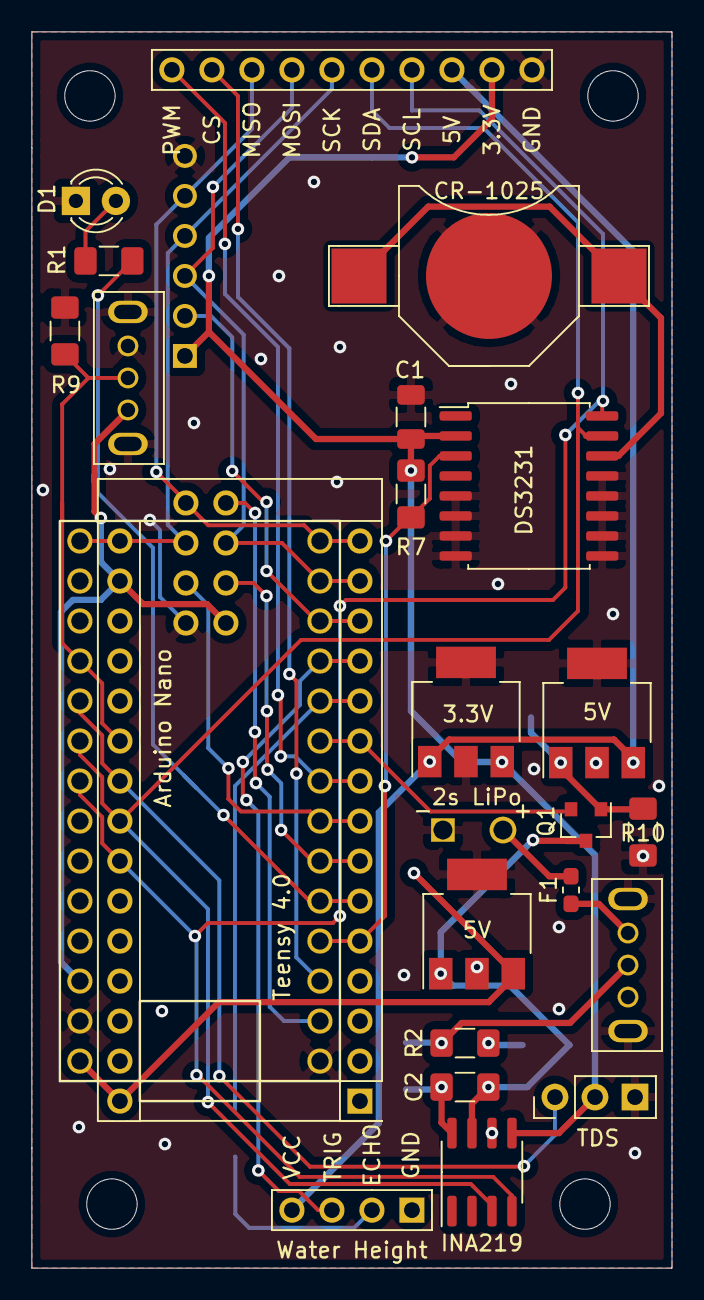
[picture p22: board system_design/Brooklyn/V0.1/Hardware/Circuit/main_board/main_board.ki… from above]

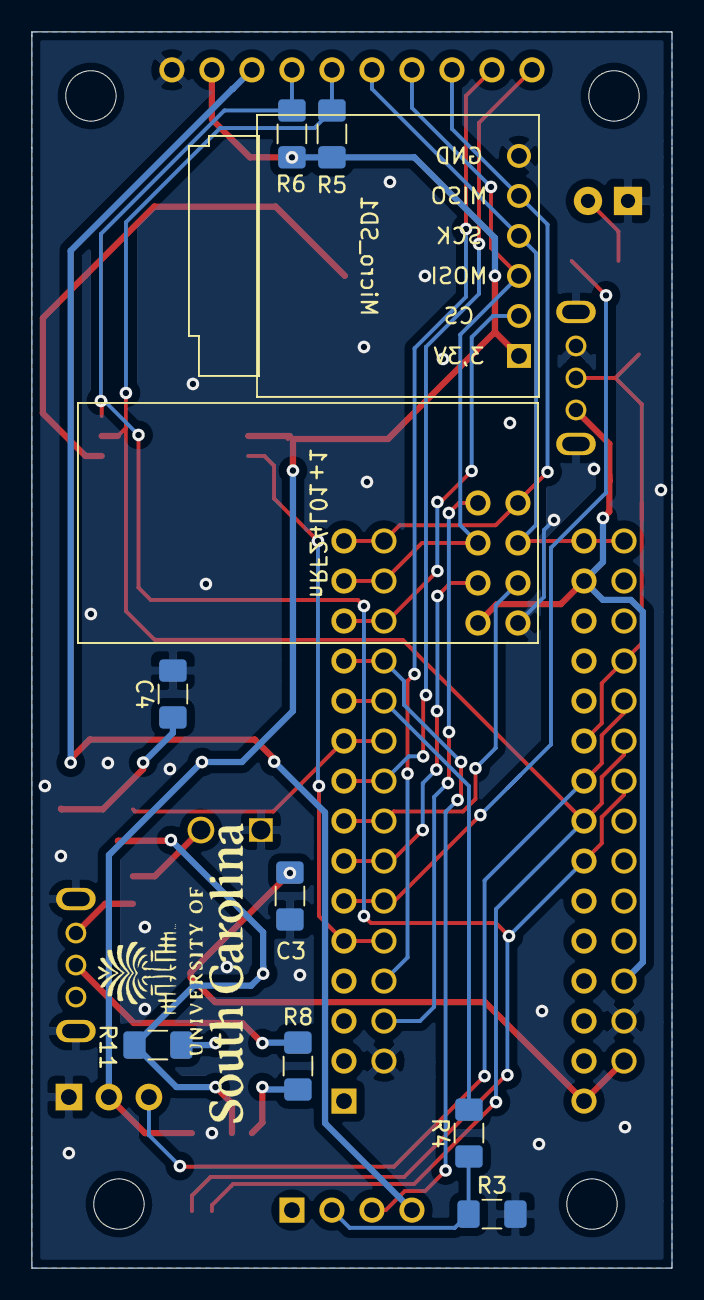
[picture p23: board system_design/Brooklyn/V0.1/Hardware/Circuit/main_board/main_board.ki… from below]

Board: 2 copper layers, 40.6 x 78.5 mm, 34 parts (8 on the bottom side), 33 nets.

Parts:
2s LiPo: XP60PW; XT60PW
3.3V, 5V, 5V#2: KA78M05_TO252; SOT-223-3_TabPin2
Arduino Nano: Arduino_Nano_v2.x-MCU_Module; Arduino_Nano
C1: C; R_1206_3216Metric
C2, C3, C4: C; R_1206_3216Metric_Pad1.42x1.75mm_HandSolder
CR-1025: Battery_Cell; battery_holder_10mm
D1: LED; LED_D3.0mm
DS3231: DS3231M; SOIC-16W_7.5x10.3mm_P1.27mm
F1: Fuse; R_0603_1608Metric_Pad1.05x0.95mm_HandSolder
INA219: INA219AxD; SOIC-8_3.9x4.9mm_P1.27mm
Micro_SD1: small_microSD
Q1: 2N2219; SOT-23
R1: 1k; R_1206_3216Metric_Pad1.42x1.75mm_HandSolder
R2: Rs; R_1206_3216Metric_Pad1.42x1.75mm_HandSolder
R3, R4: 2.2k; R_1206_3216Metric_Pad1.42x1.75mm_HandSolder
R5, R6, R7: 4.7k; R_1206_3216Metric_Pad1.42x1.75mm_HandSolder
R8, R11: 10; R_1206_3216Metric_Pad1.42x1.75mm_HandSolder
R9, R10: 10k; R_1206_3216Metric_Pad1.42x1.75mm_HandSolder
TDS: tds_3pin; PinHeader_1x03_P2.54mm_Vertical
Teensy 4.0: Teensy4.0; teensy4.0
Water Height: HCSR04
nRF24L01+1: nRF24L01+
switch1: grounded_switch
switch2: grounded_DIP_switch; grounded_switch
top_rail1: top_rail

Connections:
GND: 2s LiPo.1, 3.3V.2, 5V.2, 5V#2.2, C1.2, C3.1, C4.2, CR-1025.2, D1.1, DS3231.5, DS3231.6, DS3231.7, DS3231.8, DS3231.9, DS3231.10, DS3231.11, DS3231.12, DS3231.13, INA219.6, Micro_SD1.6, R3.2, R9.2, R10.1, TDS.3, Teensy 4.0.1, Teensy 4.0.32, nRF24L01+1.5, switch1.4, switch1.5, switch2.3, switch2.4, switch2.5, top_rail1.9
unnamed: Arduino Nano.5, DS3231.3, R7.2, Teensy 4.0.4
unnamed: Arduino Nano.6, R1.1, Teensy 4.0.5
unnamed: Arduino Nano.7, Teensy 4.0.6, nRF24L01+1.2
unnamed: Arduino Nano.8, Teensy 4.0.7, nRF24L01+1.6
unnamed: Arduino Nano.9, Teensy 4.0.8, top_rail1.10
unnamed: Arduino Nano.10, Q1.2, Teensy 4.0.9
unnamed: Arduino Nano.11, R4.2, Teensy 4.0.10
unnamed: Arduino Nano.12, Teensy 4.0.11, Water Height.3
unnamed: Arduino Nano.13, Micro_SD1.2, Teensy 4.0.12
unnamed: Arduino Nano.14, Micro_SD1.3, Teensy 4.0.13, nRF24L01+1.3, top_rail1.3
unnamed: Arduino Nano.15, Micro_SD1.5, Teensy 4.0.14, nRF24L01+1.8, top_rail1.2
unnamed: Arduino Nano.16, Micro_SD1.4, Teensy 4.0.20, nRF24L01+1.7, top_rail1.4
unnamed: Arduino Nano.17, Teensy 4.0.31, nRF24L01+1.1, switch2.1
unnamed: Arduino Nano.21, R9.1, Teensy 4.0.23, switch2.2
unnamed: Arduino Nano.22, TDS.1, Teensy 4.0.24
unnamed: Arduino Nano.23, DS3231.15, INA219.3, R5.2, Teensy 4.0.25, top_rail1.5
unnamed: Arduino Nano.24, DS3231.16, INA219.4, R6.2, Teensy 4.0.26, top_rail1.6
unnamed: 5V.3, Arduino Nano.30, C3.2, Teensy 4.0.33
unnamed: CR-1025.1, DS3231.14
unnamed: 3.3V.3, C1.1, DS3231.2, INA219.5, Micro_SD1.1, R5.1, R6.1, R7.1, TDS.2, top_rail1.8
unnamed: C2.1, INA219.8, R8.1
unnamed: 5V.1, C2.2, INA219.7, Q1.3, R11.1
unnamed: 5V#2.1, C4.1, Q1.1, R10.2
unnamed: D1.2, R1.2
unnamed: F1.1, switch1.1
unnamed: 2s LiPo.2, F1.2
unnamed: R2.1, R8.2, switch1.2
unnamed: R3.1, R4.1, Water Height.2
unnamed: R2.2, R11.2
unnamed: Teensy 4.0.2, nRF24L01+1.4
unnamed: Teensy 4.0.3, top_rail1.1
unnamed: 3.3V.1, 5V#2.3, Water Height.4, top_rail1.7

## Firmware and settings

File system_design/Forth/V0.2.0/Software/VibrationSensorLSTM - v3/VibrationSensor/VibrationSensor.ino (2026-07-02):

#include <SCA3300.h>
#include <SD.h>
#include <math.h>
#include <string.h>
#include <stdlib.h>

/* ============================================================
   Teensy 4.0 UAV Sensor Package
   Buffered acquisition + SD-based LSTM compensation

   Required model files on SD card root:
   WI.CSV
   WH.CSV
   B.CSV
   FCW.CSV
   FCB.CSV
   NORM.CSV
   META.CSV
   ============================================================ */

constexpr uint8_t SCA3300_CHIP_SELECT = 1;
constexpr uint8_t SD_CHIP_SELECT = 4;
constexpr uint8_t LED_PIN = 3;
constexpr uint8_t WRITE_PIN = 2;

constexpr uint32_t SPI_SPEED = 2000000;
constexpr size_t DATA_POINT = 69000;

float targetFrequency = 400.0;
uint32_t DELAY_TIME = (1000000.0 / targetFrequency) - 35.0;

constexpr uint32_t LED_FLASH_INTERVAL = 250;

/* ---------------- LSTM Settings ---------------- */

#define INPUT_SIZE 1
#define HIDDEN_SIZE 50
#define GATE_SIZE (4 * HIDDEN_SIZE)

/* ---------------- Dynamic LSTM Memory ---------------- */

float* Wi  = nullptr;
float* Wh  = nullptr;
float* B   = nullptr;
float* Wfc = nullptr;
float* h   = nullptr;
float* c   = nullptr;

float Bfc = 0.0;

float inputMu = 0.0;
float inputSig = 1.0;
float targetMu = 0.0;
float targetSig = 1.0;

/* ---------------- Sensor Axis ---------------- */

// Top sensor package:
const sca3300_library::Axis MEASURE_AXIS = sca3300_library::Axis::Z;
constexpr int AXIS_SIGN = 1;

// Bottom sensor package:
// const sca3300_library::Axis MEASURE_AXIS = sca3300_library::Axis::Y;
// constexpr int AXIS_SIGN = -1;

sca3300_library::SCA3300 sca3300(
  SCA3300_CHIP_SELECT,
  SPI_SPEED,
  sca3300_library::OperationMode::MODE3,
  true
);

unsigned int fileNameCount = 0;

/* ---------------- Function Prototypes ---------------- */

void listFiles();
void errorBlink();

void findNextFileNames(char* rawFileName, char* compensatedFileName);

bool allocateAcquisitionBuffers(int16_t*& data, uint32_t*& timeStamps);
void freeAcquisitionBuffers(int16_t*& data, uint32_t*& timeStamps);

void recordData(int16_t* data, uint32_t* timeStamps, uint32_t delayTime);

void writeRawCSV(int16_t* data,
                 uint32_t* timeStamps,
                 sca3300_library::OperationMode operationMode,
                 const char* fileName);

bool allocateLSTMModel();
void freeLSTMModel();

bool loadLSTMModelFromSD();
bool loadMatrixCSV(const char* fileName, float* destination, int rows, int cols);
bool loadVectorCSV(const char* fileName, float* destination, int length);

void resetLSTMState();
float runLSTMStep(float x);
float sigmoidFast(float x);

void compensateRawFile(const char* rawFileName, const char* compensatedFileName);

bool readLine(File& file, char* buffer, size_t maxLen);
int parseCSVFloats(char* line, float* values, int maxValues);

/* ============================================================
   Setup
   ============================================================ */

void setup() {
  Serial.begin(9600);
  delay(1500);

  pinMode(LED_PIN, OUTPUT);
  pinMode(WRITE_PIN, INPUT);

  digitalWrite(LED_PIN, LOW);

  Serial.println("Initializing SD Card...");

  if (!SD.begin(SD_CHIP_SELECT)) {
    Serial.println("Card Failed, or NOT Present");

    while (true) {
      digitalWrite(LED_PIN, HIGH);
      delay(100);
      digitalWrite(LED_PIN, LOW);
      delay(100);
    }
  }

  Serial.println("SD Card Initialized.");

  listFiles();

  sca3300.initChip();

  Serial.println("System Ready.");
  Serial.print("Sampling rate: ");
  Serial.print(targetFrequency);
  Serial.print(" S/s; Test time: ");
  Serial.print(DATA_POINT / targetFrequency);
  Serial.println(" seconds.");
  Serial.println("Waiting For Trigger...");
}

/* ============================================================
   Loop
   ============================================================ */

void loop() {

  /*
  while (digitalRead(WRITE_PIN) == LOW) {
    digitalWrite(LED_PIN, LOW);
  }
  */

  Serial.println("Trigger Received");

  char rawFileName[13];
  char compensatedFileName[13];

  findNextFileNames(rawFileName, compensatedFileName);

  int16_t* data = nullptr;
  uint32_t* timeStamps = nullptr;

  if (!allocateAcquisitionBuffers(data, timeStamps)) {
    Serial.println("ERROR: Could not allocate acquisition buffers.");
    errorBlink();
    return;
  }

  digitalWrite(LED_PIN, HIGH);

  recordData(data, timeStamps, DELAY_TIME);

  writeRawCSV(data,
              timeStamps,
              sca3300.getOperationMode(),
              rawFileName);

  freeAcquisitionBuffers(data, timeStamps);

  Serial.println("Acquisition buffers released.");

  if (!allocateLSTMModel()) {
    Serial.println("ERROR: Could not allocate LSTM model memory.");
    errorBlink();
    return;
  }

  Serial.println("Loading LSTM model from SD...");

  if (!loadLSTMModelFromSD()) {
    Serial.println("ERROR: Failed to load LSTM model.");
    freeLSTMModel();
    errorBlink();
    return;
  }

  Serial.println("LSTM model loaded successfully.");

  Serial.println("Running on-device LSTM compensation...");

  compensateRawFile(rawFileName, compensatedFileName);

  freeLSTMModel();

  digitalWrite(LED_PIN, LOW);

  Serial.println("Logging and compensation complete.");
  Serial.print("Raw file: ");
  Serial.println(rawFileName);
  Serial.print("Compensated file: ");
  Serial.println(compensatedFileName);

  Serial.println("Waiting For Trigger Release");

  while (digitalRead(WRITE_PIN) == HIGH) {
    delay(10);
  }

  for (int i = 0; i < 3; i++) {
    digitalWrite(LED_PIN, HIGH);
    delay(500);
    digitalWrite(LED_PIN, LOW);
    delay(500);
  }

  Serial.println("Ready For New Trigger");
}

/* ============================================================
   Diagnostics
   ============================================================ */

void listFiles() {
  File root = SD.open("/");

  Serial.println();
  Serial.println("========== SD CARD CONTENTS ==========");

  while (true) {
    File entry = root.openNextFile();

    if (!entry) {
      break;
    }

    Serial.print(entry.name());
    Serial.print("    ");
    Serial.println(entry.size());

    entry.close();
  }

  root.close();

  Serial.println("======================================");
  Serial.println();
}

void errorBlink() {
  while (true) {
    digitalWrite(LED_PIN, HIGH);
    delay(150);
    digitalWrite(LED_PIN, LOW);
    delay(150);
  }
}

/* ============================================================
   File Naming
   ============================================================ */

void findNextFileNames(char* rawFileName, char* compensatedFileName) {
  while (true) {
    sprintf(rawFileName, "R%03d.CSV", fileNameCount);
    sprintf(compensatedFileName, "C%03d.CSV", fileNameCount);

    if (!SD.exists(rawFileName) && !SD.exists(compensatedFileName)) {
      fileNameCount++;
      return;
    }

    fileNameCount++;
  }
}

/* ============================================================
   Acquisition Buffer Allocation
   ============================================================ */

bool allocateAcquisitionBuffers(int16_t*& data, uint32_t*& timeStamps) {
  data = new int16_t[DATA_POINT];

  if (data == nullptr) {
    return false;
  }

  timeStamps = new uint32_t[DATA_POINT];

  if (timeStamps == nullptr) {
    delete[] data;
    data = nullptr;
    return false;
  }

  return true;
}

void freeAcquisitionBuffers(int16_t*& data, uint32_t*& timeStamps) {
  if (data != nullptr) {
    delete[] data;
    data = nullptr;
  }

  if (timeStamps != nullptr) {
    delete[] timeStamps;
    timeStamps = nullptr;
  }
}

/* ============================================================
   Data Acquisition
   ============================================================ */

void recordData(int16_t* data, uint32_t* timeStamps, uint32_t delayTime) {
  Serial.println("Start Recording");

  for (size_t i = 0; i < DATA_POINT; ++i) {
    data[i] = sca3300.getAccelRaw(MEASURE_AXIS);
    timeStamps[i] = micros();
    delayMicroseconds(delayTime);
  }

  Serial.println("Finish Recording");
}

/* ============================================================
   Write Raw CSV
   ============================================================ */

void writeRawCSV(int16_t* data,
                 uint32_t* timeStamps,
                 sca3300_library::OperationMode operationMode,
                 const char* fileName) {
  File dataFile = SD.open(fileName, FILE_WRITE);

  if (!dataFile) {
    Serial.print("ERROR: Could Not Create ");
    Serial.println(fileName);
    return;
  }

  Serial.print("Writing raw data to SD: ");
  Serial.println(fileName);

  dataFile.println("time_us,raw_accel");

  bool ledState = HIGH;
  unsigned long lastBlinkTime = millis();

  uint32_t startTime = timeStamps[0];

  for (size_t i = 0; i < DATA_POINT; ++i) {
    unsigned long currentTime = millis();

    if (currentTime - lastBlinkTime >= LED_FLASH_INTERVAL) {
      ledState = !ledState;
      digitalWrite(LED_PIN, ledState);
      lastBlinkTime = currentTime;
    }

    uint32_t relativeTime = timeStamps[i] - startTime;

    double rawAccel = sca3300_library::SCA3300::convertRawAccelToAccel(
      data[i],
      operationMode
    );

    rawAccel = AXIS_SIGN * rawAccel;

    dataFile.print(relativeTime);
    dataFile.print(",");
    dataFile.println(rawAccel, 7);
  }

  dataFile.flush();
  dataFile.close();

  Serial.println("Finished writing raw data.");
}

/* ============================================================
   LSTM Model Allocation
   ============================================================ */

bool allocateLSTMModel() {
  Wi  = new float[GATE_SIZE * INPUT_SIZE];
  Wh  = new float[GATE_SIZE * HIDDEN_SIZE];
  B   = new float[GATE_SIZE];
  Wfc = new float[HIDDEN_SIZE];
  h   = new float[HIDDEN_SIZE];
  c   = new float[HIDDEN_SIZE];

  if (Wi == nullptr || Wh == nullptr || B == nullptr ||
      Wfc == nullptr || h == nullptr || c == nullptr) {
    freeLSTMModel();
    return false;
  }

  return true;
}

void freeLSTMModel() {
  if (Wi != nullptr) {
    delete[] Wi;
    Wi = nullptr;
  }

  if (Wh != nullptr) {
    delete[] Wh;
    Wh = nullptr;
  }

  if (B != nullptr) {
    delete[] B;
    B = nullptr;
  }

  if (Wfc != nullptr) {
    delete[] Wfc;
    Wfc = nullptr;
  }

  if (h != nullptr) {
    delete[] h;
    h = nullptr;
  }

  if (c != nullptr) {
    delete[] c;
    c = nullptr;
  }
}

/* ============================================================
   Load LSTM Model
   ============================================================ */

bool loadLSTMModelFromSD() {
  bool ok = true;

  ok &= loadMatrixCSV("WI.CSV", Wi, GATE_SIZE, INPUT_SIZE);
  ok &= loadMatrixCSV("WH.CSV", Wh, GATE_SIZE, HIDDEN_SIZE);
  ok &= loadVectorCSV("B.CSV", B, GATE_SIZE);
  ok &= loadVectorCSV("FCW.CSV", Wfc, HIDDEN_SIZE);
  ok &= loadVectorCSV("FCB.CSV", &Bfc, 1);

  float normData[4];

  ok &= loadVectorCSV("NORM.CSV", normData, 4);

  inputMu = normData[0];
  inputSig = normData[1];
  targetMu = normData[2];
  targetSig = normData[3];

  Serial.println("Model parameter summary:");
  Serial.print("inputMu: "); Serial.println(inputMu, 8);
  Serial.print("inputSig: "); Serial.println(inputSig, 8);
  Serial.print("targetMu: "); Serial.println(targetMu, 8);
  Serial.print("targetSig: "); Serial.println(targetSig, 8);
  Serial.print("Wi[0]: "); Serial.println(Wi[0], 8);
  Serial.print("Wh[0]: "); Serial.println(Wh[0], 8);
  Serial.print("B[0]: "); Serial.println(B[0], 8);
  Serial.print("Wfc[0]: "); Serial.println(Wfc[0], 8);
  Serial.print("Bfc: "); Serial.println(Bfc, 8);

  return ok;
}

/* ============================================================
   CSV Loading Utilities
   ============================================================ */

bool loadMatrixCSV(const char* fileName, float* destination, int rows, int cols) {
  File file = SD.open(fileName, FILE_READ);

  if (!file) {
    Serial.print("ERROR opening ");
    Serial.println(fileName);
    return false;
  }

  Serial.print("Loading ");
  Serial.println(fileName);

  const int MAX_LINE = 2048;
  char line[MAX_LINE];

  int row = 0;

  while (file.available() && row < rows) {
    if (!readLine(file, line, MAX_LINE)) {
      break;
    }

    if (strlen(line) == 0) {
      continue;
    }

    float values[HIDDEN_SIZE];

    int n = parseCSVFloats(line, values, cols);

    if (n < cols) {
      Serial.print("ERROR parsing ");
      Serial.print(fileName);
      Serial.print(" row ");
      Serial.println(row);
      file.close();
      return false;
    }

    for (int col = 0; col < cols; col++) {
      destination[row * cols + col] = values[col];
    }

    row++;
  }

  file.close();

  if (row != rows) {
    Serial.print("ERROR: Expected rows ");
    Serial.print(rows);
    Serial.print(" but read ");
    Serial.println(row);
    return false;
  }

  return true;
}

bool loadVectorCSV(const char* fileName, float* destination, int length) {
  File file = SD.open(fileName, FILE_READ);

  if (!file) {
    Serial.print("ERROR opening ");
    Serial.println(fileName);
    return false;
  }

  Serial.print("Loading ");
  Serial.println(fileName);

  const int MAX_LINE = 2048;
  char line[MAX_LINE];

  int index = 0;

  while (file.available() && index < length) {
    if (!readLine(file, line, MAX_LINE)) {
      break;
    }

    if (strlen(line) == 0) {
      continue;
    }

    char* token = strtok(line, ",");

    while (token != NULL && index < length) {
      destination[index] = atof(token);
      index++;
      token = strtok(NULL, ",");
    }
  }

  file.close();

  if (index != length) {
    Serial.print("ERROR: Expected ");
    Serial.print(length);
    Serial.print(" values from ");
    Serial.print(fileName);
    Serial.print(" but read ");
    Serial.println(index);
    return false;
  }

  return true;
}

bool readLine(File& file, char* buffer, size_t maxLen) {
  size_t index = 0;

  while (file.available() && index < maxLen - 1) {
    char ch = file.read();

    if (ch == '\r') {
      continue;
    }

    if (ch == '\n') {
      break;
    }

    buffer[index++] = ch;
  }

  buffer[index] = '\0';

  return index > 0;
}

int parseCSVFloats(char* line, float* values, int maxValues) {
  int count = 0;

  char* token = strtok(line, ",");

  while (token != NULL && count < maxValues) {
    values[count] = atof(token);
    count++;
    token = strtok(NULL, ",");
  }

  return count;
}

/* ============================================================
   LSTM Inference
   ============================================================ */

void resetLSTMState() {
  for (int i = 0; i < HIDDEN_SIZE; i++) {
    h[i] = 0.0f;
    c[i] = 0.0f;
  }
}

float runLSTMStep(float x) {
  float xNorm = (x - inputMu) / inputSig;

  float iGate[HIDDEN_SIZE];
  float fGate[HIDDEN_SIZE];
  float gGate[HIDDEN_SIZE];
  float oGate[HIDDEN_SIZE];

  for (int j = 0; j < HIDDEN_SIZE; j++) {
    float zi = Wi[j * INPUT_SIZE] * xNorm + B[j];
    float zf = Wi[(HIDDEN_SIZE + j) * INPUT_SIZE] * xNorm + B[HIDDEN_SIZE + j];
    float zg = Wi[(2 * HIDDEN_SIZE + j) * INPUT_SIZE] * xNorm + B[2 * HIDDEN_SIZE + j];
    float zo = Wi[(3 * HIDDEN_SIZE + j) * INPUT_SIZE] * xNorm + B[3 * HIDDEN_SIZE + j];

    for (int k = 0; k < HIDDEN_SIZE; k++) {
      zi += Wh[j * HIDDEN_SIZE + k] * h[k];
      zf += Wh[(HIDDEN_SIZE + j) * HIDDEN_SIZE + k] * h[k];
      zg += Wh[(2 * HIDDEN_SIZE + j) * HIDDEN_SIZE + k] * h[k];
      zo += Wh[(3 * HIDDEN_SIZE + j) * HIDDEN_SIZE + k] * h[k];
    }

    iGate[j] = sigmoidFast(zi);
    fGate[j] = sigmoidFast(zf);
    gGate[j] = tanhf(zg);
    oGate[j] = sigmoidFast(zo);
  }

  for (int j = 0; j < HIDDEN_SIZE; j++) {
    c[j] = fGate[j] * c[j] + iGate[j] * gGate[j];
    h[j] = oGate[j] * tanhf(c[j]);
  }

  float yNorm = Bfc;

  for (int j = 0; j < HIDDEN_SIZE; j++) {
    yNorm += Wfc[j] * h[j];
  }

  float y = yNorm * targetSig + targetMu;

  return y;
}

float sigmoidFast(float x) {
  if (x > 20.0f) return 1.0f;
  if (x < -20.0f) return 0.0f;

  return 1.0f / (1.0f + expf(-x));
}

/* ============================================================
   Compensate Raw File
   ============================================================ */

void compensateRawFile(const char* rawFileName, const char* compensatedFileName) {
  File rawFile = SD.open(rawFileName, FILE_READ);

  if (!rawFile) {
    Serial.print("ERROR opening raw file: ");
    Serial.println(rawFileName);
    return;
  }

  File compensatedFile = SD.open(compensatedFileName, FILE_WRITE);

  if (!compensatedFile) {
    Serial.print("ERROR creating compensated file: ");
    Serial.println(compensatedFileName);
    rawFile.close();
    return;
  }

  compensatedFile.println("time_us,raw_accel,lstm_compensated_accel");

  resetLSTMState();

  const int MAX_LINE = 128;
  char line[MAX_LINE];

  bool firstLine = true;
  size_t sampleCount = 0;

  bool ledState = HIGH;
  unsigned long lastBlinkTime = millis();

  while (rawFile.available()) {
    if (!readLine(rawFile, line, MAX_LINE)) {
      continue;
    }

    if (strlen(line) == 0) {
      continue;
    }

    if (firstLine) {
      firstLine = false;

      if (strstr(line, "time") != NULL) {
        continue;
      }
    }

    char* tokenTime = strtok(line, ",");
    char* tokenRaw = strtok(NULL, ",");

    if (tokenTime == NULL || tokenRaw == NULL) {
      continue;
    }

    uint32_t timeUS = strtoul(tokenTime, NULL, 10);
    float rawAccel = atof(tokenRaw);

    float compensatedAccel = runLSTMStep(rawAccel);

    compensatedFile.print(timeUS);
    compensatedFile.print(",");
    compensatedFile.print(rawAccel, 7);
    compensatedFile.print(",");
    compensatedFile.println(compensatedAccel, 7);

    sampleCount++;

    unsigned long currentTime = millis();

    if (currentTime - lastBlinkTime >= LED_FLASH_INTERVAL) {
      ledState = !ledState;
      digitalWrite(LED_PIN, ledState);
      lastBlinkTime = currentTime;
    }
  }

  rawFile.close();
  compensatedFile.flush();
  compensatedFile.close();

  Serial.print("Compensated samples written: ");
  Serial.println(sampleCount);
}

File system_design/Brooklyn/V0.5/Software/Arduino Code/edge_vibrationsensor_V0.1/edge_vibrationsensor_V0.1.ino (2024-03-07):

/*
 * Vibration Sensor Package with edge computing Version: 0.1
 * - This code accurately detects the first mode, but attempts the first 3 modes sometimes unsuccessfully
 */


#include <SCA3300.h>
#include <SD.h>
#include <SPI.h>
#include "arduinoFFT.h"

arduinoFFT FFT; // Create FFT object

File myFile;

boolean Trig = 0;
unsigned int fileNameCount = 0;

const uint8_t LED_PIN = 3; // Indicator LED pin number
const uint8_t SCA3300_CHIP_SELECT = 1;  //Current PCB Chip Select
const uint8_t SD_CHIP_SELECT = 4;    //PCB Chip Select
const uint8_t Trig_PIN = 2;

constexpr uint32_t SPI_SPEED = 2000000;
constexpr size_t DATA_POINT = 16384;     // Must be a power of 2
const uint16_t samples = 16384; // Must be a power of 2

constexpr uint32_t Freq = 1600; // Sampling rate of the accelerometer in Samples/s (change this to change test time)
const double samplingFrequency = 1600; // Sampling frequency for FFT
constexpr uint32_t DELAY_TIME = static_cast<uint32_t>(((1.0/Freq)-.00003487893522)*1000000);

double vReal[samples]; // Real part of the FFT input
double vImag[samples]; // Imaginary part of the FFT input
int dataCount = 0;

sca3300_library::SCA3300 sca3300(SCA3300_CHIP_SELECT, SPI_SPEED, sca3300_library::OperationMode::MODE3, true); // MODE#1 is 3G

void recordData(int16_t* data, uint32_t* timeStamps, uint32_t delayTime);
void writeSDConverted(int16_t* data, uint32_t* timeStamps, sca3300_library::OperationMode operationMode, char* fileName);
void printDataConverted(int16_t* data, uint32_t* timeStamps, sca3300_library::OperationMode operationMode);

void setup() {
  delay(5000);
  Serial.begin(9600);
  pinMode(Trig_PIN, INPUT);
  pinMode(LED_PIN, OUTPUT);
  Serial.println("Initializing SD Card...");
  if (!SD.begin(SD_CHIP_SELECT)) {
    Serial.println("Card Failed, or NOT Present");
    return;
  }
  Serial.println("SD Card Initialized.");
  sca3300.initChip();
  Serial.print("Sampling Frequency:");
  Serial.println(1/((DELAY_TIME*.000001)+.00003487893522));
  Serial.print("Test Length (s):");
  Serial.println(DATA_POINT*((DELAY_TIME*.000001)+.00003487893522));
}

void loop() {
  Trig = 1; // Replace with digitalRead(Trig_PIN); for actual trigger
  if (Trig == 1) {
    int16_t data[DATA_POINT];
    uint32_t timeStamps[DATA_POINT];
    digitalWrite(LED_PIN, HIGH);
    recordData(data, timeStamps, DELAY_TIME);
    char fileName[13];
    sprintf(fileName, "DATA%03d.csv", fileNameCount);
//    fileNameCount++;
    writeSDConverted(data, timeStamps, sca3300.getOperationMode(), fileName);
    printDataConverted(data, timeStamps, sca3300.getOperationMode());

    // Open the file for reading:
    myFile = SD.open(fileName);
    if (myFile) {
      Serial.print("Reading from ");
      Serial.println(fileName);
      
      double sum = 0;
      int dataCount = 0;
      
      while (myFile.available() && dataCount < samples) {
      String line = myFile.readStringUntil('\n');
      int commaIndex = line.indexOf(',');
      if (commaIndex != -1) {
        String accelString = line.substring(commaIndex + 1);
        vReal[dataCount] = accelString.toFloat();
        vImag[dataCount] = 0;
        sum += vReal[dataCount];
        dataCount++;
      }
    }
    myFile.close();
    Serial.println("Finished reading file");
    delay(1000);
    double average = sum/dataCount;

    for(int i = 0; i < dataCount; i++){
      vReal[i] -= average;
    }

    // Perform FFT
    FFT.Windowing(vReal, samples, FFT_WIN_TYP_HAMMING, FFT_FORWARD);
    FFT.Compute(vReal, vImag, samples, FFT_FORWARD);
    FFT.ComplexToMagnitude(vReal, vImag, samples);
    delay(1000);

//    for (int i = 0; i < (samples >> 1); i++) {
//      Serial.print("Frequency ");
//      Serial.print((i * 1.0 * samplingFrequency) / samples, 1);
//      Serial.print(" Hz, Magnitude: ");
//      Serial.println(vReal[i], 4);
//    }

   File FFTFile = SD.open("FFT001.csv", FILE_WRITE);
    if (FFTFile) {
      Serial.println("Writing FFT values to FFT file");
      for (int i = 0; i < (samples >> 1); i++) {
        FFTFile.print((i * 1.0 * samplingFrequency) / samples, 1); // Replace 500 with your actual sampling frequency
        FFTFile.print(",");
        FFTFile.println(vReal[i], 4);
      }
      FFTFile.close();
      Serial.println("Finished writing FFT values to file");
    } else {
      Serial.println("Error opening FFT file for writing");
    }

    // Apply smoothing
//    int windowSize = 5; // Choose an appropriate window size
//    double temp[samples]; // Temporary array to store the smoothed data
//
//    // Apply moving average on the magnitude data
//    for (int i = 0; i < samples; i++) {
//      temp[i] = 0; // Initialize temporary storage
//      for (int j = -windowSize / 2; j <= windowSize / 2; j++) {
//        int index = i + j;
//        if (index < 0 || index >= samples) continue; // Skip out-of-bounds indices
//        temp[i] += vReal[index];
//      }
//      temp[i] /= windowSize; // Calculate the average
//    }
//
//    for (int i = 0; i < samples; i++) {
//      vReal[i] = temp[i];
//    }

    // Peak Detection
    const int peakThreshold = 10; // Set this based on your data
    int peakCount = 0;
    double peakFrequencies[3] = {0, 0, 0}; // Store top 3 peak frequencies
    double peakMagnitudes[3] = {0, 0, 0}; // Store top 3 peak magnitudes

    for (int i = 1; i < (samples >> 1) - 1; i++) {
      if (vReal[i] > vReal[i - 1] && vReal[i] > vReal[i + 1] && vReal[i] > peakThreshold) {
        // Check if current peak is larger than the smallest peak in top 3
        if (vReal[i] > peakMagnitudes[2]) {
          peakMagnitudes[2] = vReal[i];
          peakFrequencies[2] = (i * 1.0 * samplingFrequency) / samples;

          // Sort the top 3 peaks
          for (int j = 0; j < 2; j++) {
            if (peakMagnitudes[j] < peakMagnitudes[j + 1]) {
              double tempMag = peakMagnitudes[j];
              double tempFreq = peakFrequencies[j];
              peakMagnitudes[j] = peakMagnitudes[j + 1];
              peakFrequencies[j] = peakFrequencies[j + 1];
              peakMagnitudes[j + 1] = tempMag;
              peakFrequencies[j + 1] = tempFreq;
            }
          }
        }
      }
    }
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

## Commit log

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2022-05-23 Create PCB_HousingUnit v16.f3d
    [PCB_HousingUnit v16.f3d]
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2022-05-27 Created V0.2
    [Magdron mount.kicad_pcb, Magdron mount.sch, Sensor Package Housing Unit.stl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]
2022-05-30 cleaned up repo for EMI 2022.
    [Magdron mount.kicad_pcb, Magdron mount.sch, Sensor Package Housing Unit.stl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]
2022-06-09 Added new main board design (early stages)
    [Vibration_Sensor.kicad_pcb, Vibration_Sensor.sch, main_board.sch]
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2022-06-20 New PCB design
    [Vibration_Sensor.sch]
2022-07-07 Updated kicad and beam testing files
    [Vibration_Sensor.kicad_pcb, Vibration_Sensor.sch]
2022-08-10 Created V0.3
    [Magdron mount.kicad_pcb, Magdron mount.sch, PCB_HousingUnit.f3d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]
2022-08-16 tests
    added experimental data
    [000.CSV, 001.CSV, AccIN.csv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]
2023-01-23 V 4 Sensor package code
    [Magdron mount.kicad_pcb, Magdron mount.sch, PCB_HousingUnit.f3d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]
2023-01-23 PCB changes
    [Vibration_Sensor.sch]
2023-03-11 Changed folder name to fit the test
    The excitation you used is an impulse response.
    Driven excitation is for sinusoidal
    [000.CSV, 001.CSV]
2023-04-18 long range RF frame
    long range RF frame
    [permanent magnet sensor frame with long range RF antenna v0.4.f3d]
2023-05-29 Added files for version 0.5
    [Magdron mount.kicad_pcb, Magdron mount.sch, PCB_HousingUnit.f3d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]
2023-06-23 Changed V0.5 PCB
    [Vibration_Sensor.kicad_pcb, Vibration_Sensor.kicad_sch]
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2024-04-08 organized versions
    [Magdron mount.kicad_pcb, Magdron mount.sch, PCB_HousingUnit.f3d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]
2024-05-14 signal processing transfer
    [000.CSV, 001.CSV, AccIN.csv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]
2024-07-02 Prepared LSTM and Model
    This commit contains the LSTM implementation, the model weights in .csv
    format, and a script to generate a C++ header file to load the weights
    on the Teensy. The output is in model-weights.h.
    [b.csv, bias.csv, mergedW.csv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]
2024-07-22 Retrained Model
    [b.csv, bias.csv, mergedW.csv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]
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2024-07-23 Changed LSTM latency output unit
    Changed the unit used to measure how long it takes to process the
    accelerometer data from microseconds to milliseconds. Fixed a few
    missing escape characters.
2024-07-23 Bad data hotfix
    Bandage fix for an issue with the SCA3300 driver where it will return 0
    for a while after being turned on. This can be reverted if/when the
    driver gets fixed.
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2024-08-21 Updated weight format
    The new script expects the W and U matrices to be in seperate CSVs.
    [U.csv, W.csv, mergedW.csv]
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2024-10-08 Fix truncation issue
    Print the full precision of the float
    [dataset-collection.ino]
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2025-03-25 Update weights + add reduced model
    [U.csv, W.csv, b.csv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]
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2025-05-23 Swap rows and columns in matvec signature
    The logic here is correct, but the positional arguments led to some
    confusion.
2025-05-29 Fix dense bias bug
    [signal-compensation.ino]
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2025-06-02 Complete LSTM test program
    There's some cleaning up to do, but this will help us fix the problem
    we're having on the teensy, which is more important.
2025-06-02 Use real data for testing
    [test_data.csv]
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2025-06-04 Use true LSTM data for tests
    Compare our LSTM implementation against the Keras LSTM - a known working
    implementation. When both produce the same result, we know our LSTM is
    working.
    [measured.csv, test_data.csv, uncompressed.csv]
2025-06-05 Fix weight loading bug
    At this point, the system is fully functional.
    [signal-compensation.ino]
2025-07-01 file updates
    [Magdron mount.kicad_pcb, Magdron mount.sch, PCB_HousingUnit.f3d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]
2025-07-01 Add test model and data for reduced LSTM
    [measured_reduced.csv, reduced.csv]
2025-07-01 Fix dotproduct bug
    This bug was grandfathered in from the uncompressed LSTM. Unfortunately,
    Arduino IDE does not like relative paths, which is the reason we have to
    use seperate files to manage common functions. This means that we have
    to spend some time fixing the same bugs we had with the compressed LSTM.
2025-07-08 Fix DoF LSTM
    Unfortunately, this will be another mega-commit. Changes include
    splitting the b and c weight files, fixing a bug that caused the c state
    to not be written properly, updating the testing model, and fixing DoF
    weight matrix dimensions.
    [measured_reduced.csv, reduced.csv]
2025-07-18 Reduced LSTM firmware
    This is tested to be working. In the future, the rank will be loaded
    from the SD card as well. The idea is that all reduced models will use
    the same firmware so we don't recompile every time we need to swap out
    the model. We'll need to do this a lot. Maybe even 50 times.
    [compressed-compensation.ino]
2026-05-01 started V0.1 and v0.2 of Forth
    [Magdron mount.kicad_pcb, Magdron mount.sch, PCB_HousingUnit.f3d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]
2026-05-01 file oorganization
    [Magdron mount.kicad_pcb, Magdron mount.sch, PCB_HousingUnit.f3d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]
2026-05-01 child board works at this point
    [Vibration_Sensor.kicad_pcb, Vibration_Sensor.sch, child_board.kicad_pcb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]
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2026-05-01 KiCAD file formts updated.
    [Vibration_Sensor.kicad_pcb, Vibration_Sensor.sch, child_board.kicad_pcb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]
2026-05-01 added BOM
    [bom.csv]
2026-05-01 silk screen update
    [Vibration_Sensor.kicad_pcb, child_board.kicad_pcb]
2026-05-02 removed vibration sensor pcb files
    [Vibration_Sensor.kicad_pcb]
2026-05-12 Updates to shaker data collection code
    [measured.csv, measured_reduced.csv, reduced.csv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]
2026-05-12 removed draft BOM
    [bom.csv]
2026-05-12 cleaned up BOM
    [Bill of Materials - Vibration Sensor Package.csv]
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2026-05-12 Update Bill of Materials - Vibration Sensor Package.csv
    Updated bill of materials
    [Bill of Materials - Vibration Sensor Package.csv]
2026-05-12 Update Bill of Materials - Vibration Sensor Package.csv
    [Bill of Materials - Vibration Sensor Package.csv]
2026-05-12 Updated BOM
    [Bill of Materials - Vibration Sensor Package.csv]
2026-05-20 updated sensor frame to include permanent magnet cap
    [PCB_HousingUnit.f3d, Sensor Package Housing Unit.stl, sensor frame.f3d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]
2026-05-26 Starting code for LSTM model
    [MicrosoftStock.csv]
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2026-06-09 modified cad model
    [sensor frame.f3d]
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2026-06-09 Progress towards fixing LED bug in code
    [VibrationSensor.ino]
2026-06-09 Merging code with VibrationSensor arduino code (in progress)
    [DataCollection_DifferentAxis.ino, VibrationSensor.ino]
2026-06-10 Experimental data upload from SD cards
    [DATA000.csv, DATA001.csv, DATA002.csv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]
2026-06-10 cad files
    [sensor frame.f3d]
2026-06-10 stl file
    [sensor frame.stl]
2026-06-10 step file
    [sensor frame.step]
2026-06-10 New cap design for magnet and pcb mount wall moved inward
    [MagnetCap.ipt, UpatedSensorFrame.ipt, sensor frame.3mf]
2026-06-10 Updated Magnet Cap
    [MagnetCap.0001.ipt, MagnetCap.ipt]
2026-06-10 Updated sensor frame - indentation for easy USB plug in
    [Part4.ipt]
2026-06-11 3D print attempts for magnet cap
    [MagnetCap.0001.ipt, MagnetCap.0002.ipt, MagnetCap.3mf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]
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2026-06-11 Updated magnet cap dimensions and spectrogram image (test run)
    [MagnetCap.0002.ipt, MagnetCap.0003.ipt, MagnetCap.ipt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]
2026-06-12 new cad mod
    [sensor frame v1.f3d]
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2026-06-12 Newest data collections
    [000.csv, 001.csv]
2026-06-12 CSV data files
    [002.csv, 003.csv, 004.csv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]
2026-06-14 High-pass filter applied to graphing code & re-organized folders
    [MicrosoftStock.csv]
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2026-06-23 Attempt at new lstm recordings
    [007.csv, 008.csv, 009.csv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]
2026-06-25 Epoch 20, Batch size 16, window size 400
    [Model_Settings.csv, Predictions.csv, RunSummary.csv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]
2026-07-01 Updates to machine learning code
    [Part4Switch.step, Part4Updated.step]
